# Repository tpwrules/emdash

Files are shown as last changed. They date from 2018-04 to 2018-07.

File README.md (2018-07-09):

# Installation Instructions

The code can be built both for an included Mac/Windows/Linux simulator and the LPC11C24 ARM microcontroller. Please follow these directions carefully to learn how to build the code. I assume you have a basic knowledge of command line operation.

## Building the Base

Building the base covers downloading the code and installing Python. Python is required to build the various data files.

#### Installing Git

The Git source control system is used to hold the code. You must install the Git client in order to download the code correctly.

* Download and install Git for your operating system from <https://git-scm.com/downloads>.
    * for the Windows installer, the default options are fine
* Clone the source code
    * open a command prompt and change to the directory you want the source to be downloaded to
    * execute `git clone https://github.com/tpwrules/emdash` to get the code

#### Installing Python

The Python scripting language is used to build data files and run the simulator. These directions have been tested with Python 3.6.6. They will most likely work with 3.5 and 3.6. Python 3.7 is not yet supported.

* Download and install the latest version of Python 3.6 for your operating system from <https://www.python.org/downloads/>
    * For the Windows installer, you must check "Add Python to Path" on the first page
    * Otherwise, the default options are fine

#### Installing Python Packages

Some Python packages are required to build the data files and run the simulator. Fortunately, Python makes them easy to install.

* Open up a command prompt.
* Run the command `python3 -m pip install pypng` or `py -3 -m pip install pypng` (on Windows)
* If python isn't found, close and re-open the command prompt.

#### Testing the Base

Now that the base has been prepared, it's time to test to make sure it works.

* Open a command prompt
* Change directories to the `dashboard` directory within the downloaded code
    * Hint: you can drag that folder into the command prompt instead of typing out its location
* Run the command `build_src_gen.py`. If you see the message `SOURCE GENERATED SUCCESSFULLY`, the base has been successfully built!

## Building for LPC11C24

Building for LPC11C24 requires a working install of the base. It does not require the simulator. I use the free MCUXpresso IDE for development on the LPC11C24. You must install it and import the project in order to deploy the code onto the chip.

#### Installing MCUXpresso
You can download the MCUXpresso 10.1.1 installer from [here](https://www.nxp.com/support/developer-resources/software-development-tools/mcuxpresso-software-and-tools/mcuxpresso-integrated-development-environment-ide:MCUXpresso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). Click the Download button, log in with an NXP account (required), then select 10.1.1 under the Previous tab. Version 10.2 seems to be broken, so don't use it.

Run the installer using all the default options. Make a workspace in your favorite place.

#### Importing the code
Now that the projects are downloaded, they can be imported into MCUXpresso.

* Select File -> Import
* Select to import Git -> Projects from Git and click Next
* Select the Existing local repository source and click Next.
* Click Add... and then Browse...
* Select the `emdash` folder in the code you downloaded and click OK.
* Check the `emdash\.git` repository in the results list and click Finish. 
* Select the `emdash` repository in the repository list and click Next twice, then Finish. Code import is now complete.

#### Building the code
Build the code for the chip by selecting the dash_11c24 project in the left pane and clicking the hammer icon in the top bar. If everything works, you will see a blue `Build finished` in the bottom window.

You can then use the green bug icon to program the chip with the code and enter the debugger. The first time you click the button, you will be asked to create a run configuration. Double-click the `C/C++ (NXP Semiconductor)` option in the left pane to create the correct configuration, then click Debug in the bottom to start it. Once this is done, the green button will launch the correct configuration automatically.

## Building for Simulation
A custom simulator is included which runs the same code that is downloaded on the chip. Running the simulator requires a working install of the base, but does not require MCUXpresso or the other LPC11C24 stuff. It also requires a compatible install of the Visual C++ Build Tools, which use several gigabytes of disk space.

#### Installing Python Packages
The simulator requires some additional Python packages to operate.

* Open a command prompt
* Run the command `python3 -m pip install cffi numpy pygame` or `py -3 -m pip install cffi numpy pygame` (on Windows)

#### Installing Visual C++ Build Tools
The build tools provide the compiler used to compile the application for simulation. You try to compile the application to see if the tools are already installed. If they are not, an installation is necessary.

* Open a command prompt
* Change directories to the `dashboard/pc` directory inside the code
* Run the command `build_pc_app.py`. If there are no errors, you're finished building for simulation
* If it says you need to install Visual C++ 14.0, a compatible version of the build tools could not be found.
* Download the Build Tools for Visual Studio 2017 installer from <https://go.microsoft.com/fwlink/?linkid=840931>.
* Once the main installer loads, check 'Visual C++ build tools' under the 'Workloads' tab and click Install
* Wait quite a while. Once finished, try to run the script again. If it says `PC APP BUILT SUCCESSFULLY`, you've successfully built the simulator and you should be able to run it by running `pc_app.py`.

## Installing the CAN libraries
The LPC11C24 code has a bootloader and PC-based programming application so that the devices can be reprogrammed over CAN. The simulator can generate and receive CAN messages for test purposes. Both of these functionalities require the installation of CAN libraries for Python and the appropriate hardware drivers.

#### Installing the Python libraries
* Open up a command prompt.
* Run the command `python3 -m pip install python-can` or `py -3 -m pip install python-can` (on Windows)

#### Installing the Vector drivers
The program uses Vector CAN interfaces. You can try to run the programming application to see if the correct drivers are already installed. If the Vector interface drivers are not installed, they are available [here](https://vector.com/vi_downloadcenter_en.html?type=Driver&formular_treffer_submit=1). Download the latest version of "Vector Driver Setup".

* Open a command prompt
* Change directories to balsdjfsldf
* Run `the bootloader program`. If you see the error message `The Vector API has not been loaded`, the drivers must be installed. If you see a different error, continue to dkjfas;.
* Run the Vector Driver Setup installer program. Select and install the interface types you wish to use.
* Driver installation is now complete.

#### Configuring the Vector drivers
The Vector drivers require you to create an application configuration, which tells the application which hardware to use.

* Open the Windows Control Panel and select the Vector Hardware option.
* Select Application -> Add in the top bar to create a new application.
* Name the application `emdash`, set 1 CAN channel and 0 for all other types, and click OK.
* Select Application -> emdash in the left pane, then right-click on CAN 1 and select the interface you wish to use. You may have to plug in your interface first.
* Close the window. Configuration is now complete.

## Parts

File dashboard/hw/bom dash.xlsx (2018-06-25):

Designation | Description | Mfg/# | Mouser # | RS # | Farnell # | Substitute | Quantity
C5, C4, C2 | 10nF 0603 >5V | Any | Any | Any | Any | Yes | 3
C6, C3, C1, C15, C17, C16, C14 | 100nF 0603 >5V | Any | Any | Any | Any | Yes | 7
C7 | 1nF 0603 | Any | Any | Any | Any | Yes | 1
C8, C10, C11 | 2.2uF 0603 X5R 25V | Murata GRM188R61E225ME84D | 81-GRM188R61E225ME4D | 915-9139 | 2576752 | Yes | 3
C9 | 22uF 0603 X5R 10V | Murata GRM188R61A226ME15D | 81-GRM188R61A226ME5D | 884-7258 | 2426957 | Yes | 1
C12, C13 | 39pF 0603 16V | Vishay VJ0603A390GXJPW1BC | 77-VJ0603A390GXJPBC | 652-0055 | 2496903 | Yes | 2
D1 | 40V 1A SMA Schottky Diode | Vishay SS14-E3/61T | 625-SS14-E3 | 638-7915 | 9551280 | Yes | 1
D2 | 22V 3kW Unidirectional SMA TVS Diode | Bourns SMLJ22A-Q | 652-SMLJ22A-Q | 172-3265 | 2839633 | Yes | 1
D3 | CAN bus TVS Diode | Nexperia PESD1CAN-UX | 771-PESD1CANUX | 136-4886 | 2357118 | No | 1
J1 | 2x10 2.54mm female header | Harwin M20-7831046 | 855-M20-7831046 | 681-6842 | 7992025 | Yes | 1
J2 | 2x5 1.27mm right angle shrouded male header | Samtec SHF-105-01-L-D-RA | 649-200215120001T4LF | 901-1850 | 2505002 | Yes | 1
J3 | 1x3 2.54mm connector | TE 281698-3 | 571-281698-3 | 532-096 | 1205991 | No | 1
J4 | 1x4 2.54mm connector | TE 281698-4 | 571-281698-4 | 532-103 | 1205992 | No | 1
L1 | 10uH SMD 1.3A 200mΩ | Coilcraft LPS4018-103MRB | 994-LPS4018-103MRB | Unavailable | 2408105 | No | 1
R2, R4 | 62Ω 0603 | Panasonic ERJ-3EKF62R0V | 667-ERJ-3EKF62R0V | 122-9377 | 2303039 | Yes | 2
R3, R1 | 10kΩ 0603 | Any | Any | Any | Any | Yes | 2
R5, R6, R7 | 100Ω 0603 | Any | Any | Any | Any | Yes | 3
R8 | 100kΩ 0603 | Any | Any | Any | Any | Yes | 1
R9 | 2MΩ 0603 1/10W 1% | Vishay CRCW06032M00FKEB | 71-CRCW06032M00FKEB | 679-0169 | 2447325 | Yes | 1
R10 | 383kΩ 0603 1/10W 1% | Yaego AC0603FR-07383KL | 603-AC0603FR-07383KL | Unavailable | 2138556 | Yes | 1
R11, R12 | 36Ω 1206 1/4W | Vishay CRCW120636R0FKEA | 71-CRCW1206-36-E3 | Unavailable | 2139306 | Yes | 2
RV1 | 10k side mounted trim pot | Bourns 3362X-1-103LF | 652-3362X-1-103LF | Unavailable | 2469481 | No | 1
SW1 | 2 position 2.54mm DIP switch | APM NDS02V | 642-NDS02V | 877-2113 | 2858862 | No | 1
U1 | NXP LPC11C24 microcontroller | NXP LPC11C24FBD48/301 | 771-LPC11C24FBD48301 | 741-3939 | 2314754 | No | 1
U2 | 28V 0.5A switching converter | Texas Instruments TPS62175DQCR | 595-TPS62175DQCR | 825-6955 | 2255013 | No | 1
U3 | 300mA LDO 3.3v regulator | Texas Instruments TLV70233QDBVRQ1 | 595-TLV70233QDBVRQ1 | 796-8326 | 2323652 | No | 1
Y1 | 12MHz 18pF HC49/US SMD | ABLS-12.000MHZ-B2-T | 815-ABLS-12-B2 | 703-1809 | 1652551 | Yes | 1

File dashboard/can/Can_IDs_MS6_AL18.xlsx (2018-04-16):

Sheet: CAN-Messages
Name | Benötigt für Datenauswertung | ID | Startbit | Lenght | Datentyp | Einheit | Grid MS6 Logging[ms] | Grid MS6 Sending [ms] | Erklärung
accv |  | 0x100 | 0 | 8 | 8 Bit signed | g | 10 ms | 10 ms | Beschleunigung wird durch das Speed Signal berechnet
accx |  | 0x100 | 8 | 16 | 16 Bit signed | g | 10 ms | 10 ms | Beschleunigung in x-Richtung
accy |  | 0x100 | 24 | 16 | 16 Bit signed | g | 10 ms | 10 ms | Beschleunigung in y-Richtung
accz |  | 0x100 | 40 | 16 | 16 Bit signed | g | 10 ms | 10 ms | Beschleunigung in z-Richtung
ath |  | 0x101 | 0 | 16 | 16 Bit unsigned | % | 2 ms | 10 ms | Drosselklappenstellung
B_autoshiften_ems |  | 0x101 | 16 | 8 | 8 Bit unsigned | Bool | 2 ms | 10 ms | Bit ob Autshift aktiv ist oder nicht
B_clutch_open |  | 0x101 | 24 | 8 | 8 Bit unsigned | Bool | 2 ms | 10 ms | Bit ob Kupplung aktiv ist oder nicht
B_clutchsw |  | 0x101 | 32 | 8 | 8 Bit unsigned | Bool | 2 ms | 10 ms | Bit ob Kupplungtaster aktiv ist oder nicht
B_cutoff_gc_ems |  | 0x101 | 40 | 8 | 8 Bit unsigned | Bool | 2 ms | 10 ms | Bit ob Gearcut aktiv ist oder nicht
B_dnshevent_ems |  | 0x101 | 48 | 8 | 8 Bit unsigned | Bool | 2 ms | 10 ms | Bit ob ein Downshiftevent erkannt wurde oder nicht
B_fan_ems |  | 0x101 | 56 | 8 | 8 Bit unsigned | Bool | 2 ms | 10 ms | Bit ob die generelle Lüfteransteuerung aktiviert ist
B_fpump |  | 0x102 | 0 | 8 | 8 Bit unsigned | Bool | 1 ms | 10 ms | Bit ob die generelle Benzinpumpenansteuerung aktiviert ist
B_func_lc |  | 0x102 | 8 | 8 | 8 Bit unsigned | Bool | 2 ms | 10 ms | Lambdaregelung durch Schalter aktiv
B_gc_err_ems |  | 0x102 | 16 | 8 | 8 Bit unsigned | Bool | 2 ms | 10 ms | Zeigt an ob ein Error während einem Schaltvorgang aufgetreten ist
B_ign_all |  | 0x102 | 24 | 8 | 8 Bit unsigned | Bool | 2 ms | 10 ms | Bit alle Einspritzungen sind aktiv
B_ignoff_gc_ems |  | 0x102 | 32 | 8 | 8 Bit unsigned | Bool | 2 ms | 10 ms | Zündungsaussetzer während Gearcut aktiv
B_ignoff_launch |  | 0x102 | 40 | 8 | 8 Bit unsigned | Bool | 2 ms | 10 ms | Zündungsaussetzer während Launchcontrol aktiv
B_inj_all |  | 0x102 | 48 | 8 | 8 Bit unsigned | Bool | 2 ms | 10 ms | Zündung aktiv
B_injoff_gc_ems |  | 0x102 | 56 | 8 | 8 Bit unsigned | Bool | 2 ms | 10 ms | Einspritzungsaussetzer während Gearcut
B_injoff_launch |  | 0x103 | 0 | 8 | 8 Bit unsigned | Bool | 2 ms | 10 ms | Einspritzungsaussetzer während Launchcontrol
B_launch |  | 0x119 | 16 | 8 | 8 Bit unsigned | Bool | 2 ms | 10 ms | Bit ob Launchcontrol aktiv ist oder nicht
B_launchsw |  | 0x103 | 8 | 16 | 16 Bit signed | Bool | 2 ms | 10 ms | Bit ob der Launchcontroltaster aktiv ist oder nicht
B_shiftdnsw |  | 0x119 | 24 | 16 | 16 Bit signed | Bool | 2 ms | 10 ms | Bit ob der Taster zum Runterschalten betätigt wurde
B_shiftupsw |  | 0x119 | 40 | 16 | 16 Bit signed | Bool | 2 ms | 10 ms | Bit ob der Taster zum Hochschalten betätigt wurde
B_upshevent_ems |  | 0x103 | 24 | 16 | 16 Bit signed | Bool | 2 ms | 10 ms | Bit ob ein Upshiftevent erkannt wurde oder nicht
clutch_pwm_ems |  | 0x103 | 40 | 8 | 8 Bit signed | % | 2 ms | 10 ms | PWM Signal der Kupplung
dam_fl |  | 0x120 | 0 | 16 | 16 Bit signed | mm | 2 ms | 10 ms | Federweg Dämpfer vorne links
dam_fr |  | 0x120 | 16 | 16 | 16 Bit signed | mm | 2 ms | 10 ms | Federweg Dämpfer vorne rechts
dam_rl |  | 0x120 | 32 | 16 | 16 Bit signed | mm | 2 ms | 10 ms | Federweg Dämpfer hinten links
dam_rr |  | 0x120 | 48 | 16 | 16 Bit signed | mm | 2 ms | 10 ms | Federweg Dämpfer hinten rechts
dnlaunch |  | 0x104 | 0 | 16 | 16 Bit signed | rpm | 2 ms | 10 ms | Differenz zwischen Zeil- und aktueller Drehzahl bei Launchcontrol
dnshiftcnt |  | 0x104 | 16 | 16 | 16 Bit unsigned | [none] | 2 ms | 10 ms | Zähler für Herunterschaltvorgang
dnshifterrcnt |  | 0x104 | 32 | 16 | 16 Bit unsigned | [none] | 2 ms | 10 ms | Errorzähler für das Herunterschalten
E_autoshiftsw |  | 0x103 | 48 | 8 | 8 Bit unsigned | [none] | 2 ms | 10 ms | Error Automatic Shifting Taster
E_clutchsw |  | 0x103 | 56 | 8 | 8 Bit unsigned | [none] | 2 ms | 10 ms | Error Kupplungstaster
E_gbctrl_ems |  | 0x104 | 48 | 8 | 8 Bit unsigned | [none] | 2 ms |  | Errorzustand der Gearbox Funktion
E_launchsw |  | 0x104 | 56 | 8 | 8 Bit unsigned | [none] | 2 ms |  | Error Launchcontroltaster
E_lsu |  | 0x105 | 0 | 8 | 8 Bit unsigned | [none] | 2 ms |  | Errorzustand der Lambdasonde
E_lsuh |  | 0x105 | 8 | 8 | 8 Bit unsigned | [none] | 2 ms |  | Errorzustand des Lambdasonden Heizers
E_pbrake_f |  | 0x105 | 16 | 8 | 8 Bit unsigned | [none] | 10 ms |  | Error Bremsdruck vorne
E_pbrake_r |  | 0x105 | 24 | 8 | 8 Bit unsigned | [none] | 10 ms |  | Error Bremsdruck hinten
E_pclutch |  | 0x105 | 32 | 8 | 8 Bit unsigned | [none] | 2 ms |  | Error Kupplungsdruck
E_poil |  | 0x105 | 40 | 8 | 8 Bit unsigned | [none] | 2 ms |  | Error Öldruck
E_speed |  | 0x105 | 48 | 8 | 8 Bit unsigned | [none] | 2 ms |  | Error vom Geschwindigkeitssignal
E_steer |  | 0x105 | 56 | 8 | 8 Bit unsigned | [none] | 10 ms |  | Error Lenkwinkelsignal
E_tfuel |  | 0x106 | 0 | 8 | 8 Bit unsigned | [none] | 2 ms |  | Error Benzintemperatur
E_thr |  | 0x106 | 8 | 8 | 8 Bit unsigned | [none] | 2 ms |  | Error Drosselklappensensor
E_tmot |  | 0x106 | 16 | 8 | 8 Bit unsigned | [none] | 2 ms |  | Error Motortemperatur
E_tmot2 |  | 0x106 | 24 | 8 | 8 Bit unsigned | [none] | 2 ms |  | Error Kühlwassertemperatur am Lüfter
E_toil |  | 0x106 | 32 | 8 | 8 Bit unsigned | [none] | 2 ms |  | Error Öltemperatur
E_ub |  | 0x106 | 40 | 8 | 8 Bit unsigned | [none] | 2 ms |  | Error Batteriespannung
fan_pwm_ems |  | 0x106 | 48 | 8 | 8 Bit unsigned | % | 2 ms
flc |  | 0x106 | 56 | 8 | 8 Bit unsigned | 0.005 | 2 ms
flc_i |  | 0x107 | 0 | 8 | 8 Bit signed | 0.005 | 2 ms
flc_p |  | 0x107 | 8 | 8 | 8 Bit signed | 0.005 | 2 ms
fpump_pi_pwm |  | 0x107 | 16 | 16 | 16 Bit unsigned |  | 1 ms
fpump_pre |  | 0x107 | 32 | 16 | 16 Bit unsigned |  | 1 ms
fpump_pwm |  | 0x107 | 48 | 16 | 16 Bit unsigned |  | 1 ms
fslip_acc |  | 0x108 | 0 | 8 | 8 Bit unsigned |  | 10 ms
gc_sherr_ct_ems |  | 0x108 | 8 | 8 | 8 Bit unsigned |  | 2 ms
gc_state_ems |  | 0x108 | 16 | 8 | 8 Bit unsigned |  | 2 ms
gear |  | 0x119 | 56 | 8 | 8 Bit signed | [none] | 2 ms
gear_gc_ems |  | 0x108 | 24 | 8 | 8 Bit signed |  | 2 ms
ign_bas |  | 0x108 | 32 | 8 | 8 Bit signed | ° | 2 ms
ign_gbctrl |  | 0x108 | 40 | 16 | 16 Bit signed | ° | 2 ms
ign_gc_ems |  | 0x108 | 56 | 16 | 16 Bit signed | ° | 2 ms
ign_gc_up_off_p2_ems |  | 0x110 | 0 | 16 | 16 Bit signed | ° | 2 ms
ign_gc_up_p2_ems |  | 0x110 | 16 | 16 | 16 Bit signed | ° | 2 ms
ign_out |  | 0x110 | 32 | 16 | 16 Bit signed | ° | 2 ms
lambda |  | 0x121 | 0 | 16 | 16 Bit unsigned | [none] | 2 ms
lamnom |  | 0x111 | 0 | 8 | 8 Bit unsigned | [none] | 2 ms
ltdist |  | 0x110 | 48 | 16 | 16 Bit unsigned |  | 1 s
mfuel_fpump |  | 0x111 | 8 | 16 | 16 Bit unsigned | mg/s | 1 ms
mi_launch |  | 0x111 | 24 | 8 | 8 Bit unsigned | % | 2 ms
nmot |  | 0x121 | 16 | 16 | 16 Bit unsigned | 1/min | 2 ms
nmotcgdn_ems |  | 0x111 | 32 | 16 | 16 Bit signed |  | 2 ms
nmotcgup_ems |  | 0x111 | 48 | 16 | 16 Bit signed |  | 2 ms
pbrake_f |  | 0x112 | 0 | 16 | 16 Bit unsigned | bar | 10 ms
pbrake_r |  | 0x112 | 16 | 16 | 16 Bit unsigned | bar | 10 ms
pclutch |  | 0x112 | 32 | 16 | 16 Bit unsigned | bar | 2 ms
pfuel |  | 0x121 | 32 | 8 | 8 Bit unsigned | bar | 2 ms
poil |  | 0x121 | 40 | 8 | 8 Bit unsigned | bar | 2 ms
rl |  | 0x112 | 48 | 16 | 16 Bit unsigned | % | 2 ms
shiftdn_pwm_ems |  | 0x113 | 0 | 8 | 8 Bit signed | % | 2 ms
slip_act |  | 0x113 | 8 | 16 | 16 Bit signed | % | 10 ms
slip_nom |  | 0x113 | 24 | 8 | 8 Bit unsigned | % | 10 ms
slip_nom_r |  | 0x113 | 32 | 8 | 8 Bit unsigned | % | 10 ms
slip_rl |  | 0x113 | 40 | 16 | 16 Bit signed | % | 10 ms
slip_rr |  | 0x114 | 0 | 16 | 16 Bit signed | % | 10 ms
speed |  | 0x121 | 48 | 16 | 16 Bit unsigned | km/h | 2 ms
steer |  | 0x114 | 16 | 16 | 16 Bit signed | ° | 10 ms
tecu_cpu |  | 0x113 | 56 | 8 | 8 Bit unsigned | °C | 10 ms
tecu_sys |  | 0x114 | 32 | 8 | 8 Bit unsigned | °C | 10 ms
tecu_sys2 |  | 0x114 | 40 | 8 | 8 Bit unsigned | °C | 10 ms
tfuel |  | 0x114 | 48 | 8 | 8 Bit unsigned | °C | 2 ms
tgc_arun_ems |  | 0x115 | 0 | 16 | 16 Bit unsigned | ms | 2 ms
tgc_block_ems |  | 0x115 | 16 | 16 | 16 Bit unsigned |  | 2 ms
tgc_dn_phs1_ems |  | 0x115 | 32 | 16 | 16 Bit unsigned |  | 2 ms
tgc_up_phs1_ems |  | 0x115 | 48 | 16 | 16 Bit unsigned |  | 2 ms
tgc_up_phs2_ems |  | 0x116 | 0 | 16 | 16 Bit unsigned |  | 2 ms
THMM_01_1 |  | 0x600 | 0 | 16 | 16 Bit signed |  | 500 ms |  | Externe Temperatursensorbox
THMM_02_1 |  | 0x600 | 16 | 16 | 16 Bit signed |  | 500 ms |  | Externe Temperatursensorbox
THMM_03_1 |  | 0x600 | 32 | 16 | 16 Bit signed |  | 500 ms |  | Externe Temperatursensorbox
THMM_04_1 |  | 0x600 | 48 | 16 | 16 Bit signed |  | 500 ms |  | Externe Temperatursensorbox
THMM_05_1 |  | 0x601 | 0 | 16 | 16 Bit signed |  | 500 ms |  | Externe Temperatursensorbox
THMM_06_1 |  | 0x601 | 16 | 16 | 16 Bit signed |  | 500 ms |  | Externe Temperatursensorbox
THMM_07_1 |  | 0x601 | 32 | 16 | 16 Bit signed |  | 500 ms |  | Externe Temperatursensorbox
THMM_08_1 |  | 0x601 | 48 | 16 | 16 Bit signed |  | 501 ms |  | Externe Temperatursensorbox
tinj |  | 0x116 | 16 | 16 | 16 Bit unsigned |  | 2 ms
tint |  | 0x114 | 56 | 8 | 8 Bit unsigned |  | 2 ms
tmot |  | 0x122 | 0 | 8 | 8 Bit unsigned | °C | 2 ms
tmot2 |  | 0x122 | 8 | 8 | 8 Bit unsigned | °C | 2 ms
toil |  | 0x122 | 16 | 8 | 8 Bit unsigned | °C | 2 ms
uautoshiftsw |  | 0x116 | 32 | 16 | 16 Bit unsigned |  | 2 ms
ub |  | 0x122 | 24 | 16 | 16 Bit unsigned | V | 1 ms
uclutchsw |  | 0x116 | 48 | 16 | 16 Bit unsigned |  | 2 ms
udam_fl |  | 0x117 | 0 | 16 | 16 Bit unsigned |  | 2 ms
udam_fr |  | 0x117 | 16 | 16 | 16 Bit unsigned |  | 2 ms
udam_rl |  | 0x117 | 32 | 16 | 16 Bit unsigned |  | 2 ms
udam_rr |  | 0x117 | 48 | 16 | 16 Bit unsigned |  | 2 ms
ugearp |  | 0x118 | 0 | 16 | 16 Bit unsigned |  | 2 ms
ulaunchsw |  | 0x118 | 16 | 16 | 16 Bit unsigned |  | 2 ms
upclutch |  | 0x118 | 32 | 16 | 16 Bit unsigned |  | 2 ms
upshiftcnt |  | 0x118 | 48 | 16 | 16 Bit unsigned |  | 2 ms
upshifterrcnt |  | 0x119 | 0 | 16 | 16 Bit unsigned |  | 2 ms
vwheel_fl |  | 0x123 | 0 | 16 | 16 Bit unsigned | km/h | 2 ms
vwheel_fr |  | 0x123 | 16 | 16 | 16 Bit unsigned | km/h | 2 ms
vwheel_rl |  | 0x123 | 32 | 16 | 16 Bit unsigned | km/h | 2 ms
vwheel_rr |  | 0x123 | 48 | 16 | 16 Bit unsigned | km/h | 2 ms
B_als |  |  |  |  | 8 Bit unsigned |  | 2 ms
B_autoshiftsw |  |  |  |  | 8 Bit unsigned |  | 2 ms
B_autoshiftsw_can |  |  |  |  | 8 Bit unsigned |  | 2 ms
B_brakepos |  |  |  |  | 8 Bit unsigned |  | 2 ms
B_clutchsw_can |  |  |  |  | 8 Bit unsigned |  | 2 ms
B_cutoff_gc |  |  |  |  | 8 Bit unsigned |  | 2 ms
B_drs_ems |  |  |  |  | 8 Bit unsigned |  | 10 ms
B_drs_plaus_ems |  |  |  |  | 8 Bit unsigned |  | 10 ms
B_fpump_man |  |  |  |  | 8 Bit unsigned |  | 1 ms
B_fpump_pre |  |  |  |  | 8 Bit unsigned |  | 1 ms
B_gc |  |  |  |  | 8 Bit unsigned |  | 2 ms
B_gearlevpos |  |  |  |  | 8 Bit unsigned |  | 10 ms
B_ignoff_gc |  |  |  |  | 8 Bit unsigned | Bool | 2 ms
B_la_blocked |  |  |  |  | 8 Bit unsigned |  | 2 ms
B_lamadap |  |  |  |  | 8 Bit unsigned |  | 2 ms
B_lamadap_st |  |  |  |  | 8 Bit unsigned |  | 2 ms
B_lamnom_low |  |  |  |  | 8 Bit unsigned |  | 2 ms
B_launchsw_can |  |  |  |  | 8 Bit unsigned |  | 2 ms
B_lc |  |  |  |  | 8 Bit unsigned |  | 10 ms
B_lc_leanprot |  |  |  |  | 8 Bit unsigned |  | 2 ms
B_lcen_rl |  |  |  |  | 8 Bit unsigned |  | 2 ms
B_lsuop |  |  |  |  | 8 Bit unsigned |  | 2 ms
B_norunshifttest_ems |  |  |  |  | 8 Bit unsigned | Bool | 2 ms |  | Bit ob ein Schalttest aktiv ist, wenn der Motor aus ist
B_pfuel |  |  |  |  | 8 Bit unsigned |  | 10 ms
B_pitspeedsw |  |  |  |  | 8 Bit unsigned |  | 2 ms
B_pitspeedsw_can |  |  |  |  | 8 Bit unsigned |  | 2 ms
B_poil |  |  |  |  | 8 Bit unsigned |  | 10 ms
B_psdia_fpump_ol |  |  |  |  | 8 Bit unsigned |  | 1 ms
B_psdia_fpump_ot |  |  |  |  | 8 Bit unsigned |  | 1 ms
B_psdia_fpump_scb |  |  |  |  | 8 Bit unsigned |  | 1 ms
B_psdia_fpump_scg |  |  |  |  | 8 Bit unsigned |  | 1 ms
B_pwr |  |  |  |  | 8 Bit unsigned |  | 2 ms
B_startbrake |  |  |  |  | 8 Bit unsigned |  | 2 ms
B_stend |  |  |  |  | 8 Bit unsigned |  | 2 ms
B_tdlcen_st |  |  |  |  | 8 Bit unsigned |  | 2 ms
B_temin |  |  |  |  | 8 Bit unsigned |  | 2 ms
B_tfuel |  |  |  |  | 8 Bit unsigned |  | 10 ms
B_tmlcen |  |  |  |  | 8 Bit unsigned |  | 2 ms
B_tmot |  |  |  |  | 8 Bit unsigned |  | 10 ms
B_tmot2 |  |  |  |  | 8 Bit unsigned |  | 10 ms
B_toil |  |  |  |  | 8 Bit unsigned |  | 10 ms
B_trans_acc |  |  |  |  | 8 Bit unsigned |  | 2 ms
B_trans_dec |  |  |  |  | 8 Bit unsigned |  | 2 ms
B_transcomp |  |  |  |  | 8 Bit unsigned |  | 2 ms
B_transcomp_en |  |  |  |  | 8 Bit unsigned |  | 2 ms
B_trq_gbctrl |  |  |  |  | 8 Bit unsigned |  | 2 ms
B_trq_gbctrl_ems |  |  |  |  | 8 Bit unsigned |  | 2 ms
B_wetsw |  |  |  |  | 8 Bit unsigned |  | 2 ms
B_wetsw_can |  |  |  |  | 8 Bit unsigned |  | 2 ms
brakepos |  |  |  |  | 16 Bit signed |  | 2 ms
brakepos_cal |  |  |  |  | 16 Bit signed |  | 2 ms
brakepos_grd |  |  |  |  | 16 Bit signed |  | 2 ms
brakepos_raw |  |  |  |  | 16 Bit signed |  | 2 ms
cutoff_gc |  |  |  |  | 16 Bit unsigned |  | 2 ms
cutoff_gc_ems |  |  |  |  | 16 Bit unsigned | [none] | 2 ms
dam_fl_r |  |  |  |  | 16 Bit signed | mm | 2 ms
dam_fl_raw |  |  |  |  | 16 Bit signed | mm | 2 ms
dam_fr_r |  |  |  |  | 16 Bit signed | mm | 2 ms
dam_fr_raw |  |  |  |  | 16 Bit signed | mm | 2 ms
dam_rl_r |  |  |  |  | 16 Bit signed | mm | 2 ms
dam_rl_raw |  |  |  |  | 16 Bit signed | mm | 2 ms
dam_rr_r |  |  |  |  | 16 Bit signed | mm | 2 ms
dam_rr_raw |  |  |  |  | 16 Bit signed | mm | 2 ms
disttrip |  | 0x104 | 0 | 16 | 16 Bit unsigned | km | 1 s |  | Gefahrene Distanz seit letztem Reset des MS6
drs_freq_ems |  |  |  |  | 16 Bit unsigned |  | 10 ms
drs_pwm_ems |  |  |  |  | 8 Bit unsigned |  | 10 ms
E_autoshiftsw_can |  |  |  |  | 8 Bit unsigned | [none] | 2 ms
E_brakepos |  |  |  |  | 8 Bit unsigned | [none] | 2 ms
E_clutchsw_can |  |  |  |  | 8 Bit unsigned |  | 2 ms
E_gear_can |  |  |  |  | 8 Bit unsigned |  | 2 ms
E_gearpoti |  |  |  |  | 8 Bit unsigned |  | 2 ms
E_launchsw_can |  |  |  |  | 8 Bit unsigned |  | 2 ms
E_p22 |  |  |  |  | 8 Bit unsigned |  | 2 ms
E_p22_2 |  |  |  |  | 8 Bit unsigned |  | 2 ms
E_pitspeedsw |  |  |  |  | 8 Bit unsigned |  | 2 ms
E_pitspeedsw_can |  |  |  |  | 8 Bit unsigned |  | 2 ms
E_psdia_fpump |  |  |  |  | 8 Bit unsigned | [none] | 1 ms |  | Error Benzinpumpenansteuerung
E_psdia_fpump_ecfp |  |  |  |  | 8 Bit unsigned |  | 1 ms
E_thr2 |  |  |  |  | 8 Bit unsigned | [none] | 2 ms
E_tint |  |  |  |  | 8 Bit unsigned | [none] | 2 ms
E_tint2 |  |  |  |  | 8 Bit unsigned | [none] | 2 ms
E_wetsw |  |  |  |  | 8 Bit unsigned |  | 2 ms
E_wetsw_can |  |  |  |  | 8 Bit unsigned |  | 2 ms
f_inj_gbctrl |  |  |  |  | 16 Bit signed |  | 2 ms
f_injgc_ems |  |  |  |  | 8 Bit unsigned | 0.01 | 2 ms
Fan_Current |  |  |  |  | 16 Bit unsigned |  | 2 ms
Fan_Power |  |  |  |  | 16 Bit unsigned |  | 2 ms
Fan_Voltage |  |  |  |  | 16 Bit unsigned |  | 2 ms
fpump_2p_pwm |  |  |  |  | 16 Bit unsigned |  | 1 ms
fpump_ub |  |  |  |  | 8 Bit unsigned |  | 1 ms
Fuel_Pump_Current |  |  |  |  | 16 Bit unsigned |  | 2 ms
Fuel_Pump_Power |  |  |  |  | 16 Bit unsigned |  | 2 ms
Fuel_Pump_Voltage |  |  |  |  | 16 Bit unsigned |  | 2 ms
gearlevacc_fil |  |  |  |  | 32 Bit float |  | 2 ms
gearlevacc_max |  |  |  |  | 32 Bit unsigned |  | 2 ms
gearlevpos_cal |  |  |  |  | 16 Bit signed |  | 2 ms
gearlevpos_grd |  |  |  |  | 16 Bit signed |  | 2 ms
gearlevruck_fil |  |  |  |  | 32 Bit float |  | 2 ms
gearlevruck_max |  |  |  |  | 32 Bit unsigned |  | 2 ms
gearlevspeed_fil |  |  |  |  | 32 Bit float |  | 2 ms
gearlevspeed_max |  |  |  |  | 32 Bit unsigned |  | 2 ms
handling1 |  |  |  |  | 16 Bit signed |  | 10 ms
handling2 |  |  |  |  | 16 Bit signed |  | 10 ms
lamctrl_i |  |  |  |  | 8 Bit unsigned |  | 2 ms
lamctrl_p |  |  |  |  | 8 Bit unsigned |  | 2 ms
pclutch_r |  |  |  |  | 16 Bit unsigned |  | 2 ms
pwrstg_diag_ecc |  |  |  |  | 32 Bit unsigned |  | 2 ms
time_day |  |  |  |  | 8 Bit unsigned |  | 10 ms
time_hour |  |  |  |  | 8 Bit unsigned |  | 10 ms
time_min |  |  |  |  | 8 Bit unsigned |  | 10 ms
time_mon |  |  |  |  | 8 Bit unsigned |  | 10 ms
time_sec |  |  |  |  | 8 Bit unsigned |  | 10 ms
time_year |  |  |  |  | 8 Bit unsigned |  | 10 ms
ubrakepos |  |  |  |  | 16 Bit unsigned |  | 2 ms
ulaunchsw_can |  |  |  |  | 8 Bit unsigned |  | 2 ms
upitspeedsw |  |  |  |  | 16 Bit unsigned |  | 2 ms
upitspeedsw_can |  |  |  |  | 8 Bit unsigned |  | 2 ms
uwetsw |  |  |  |  | 16 Bit unsigned |  | 2 ms
uwetsw_can |  |  |  |  | 8 Bit unsigned |  | 2 ms
wheeltravel_fl |  |  |  |  | 32 Bit float |  | 2 ms
wheeltravel_fr |  |  |  |  | 32 Bit float |  | 2 ms
wheeltravel_rl |  |  |  |  | 32 Bit float |  | 2 ms
wheeltravel_rr |  |  |  |  | 32 Bit float |  | 2 ms

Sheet: Freie Bytes in CAN-IDs
CAN-ID | Freies Byte
0x100 | 7
0x122 | 5,6,7

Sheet: Info
Little Endian wird verstanden

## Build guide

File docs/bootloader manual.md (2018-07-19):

Welcome to the manual for the bootloader. The bootloader is designed to be easy and safe to use. This manual is divided into two sections. [Overview](#overview) describes the tasks and features of the bootloader. [PC Programmer](#pc-programmer) describes how to use the included PC-based programmer software.

The protocol is documented in `boot/src_11c24/protocol.h`.

# Overview

## Features

The bootloader allows the internal Flash memory of the LPC11C24 to be programmed over the CAN bus. The bootloader can survive a corrupt or buggy application, an incomplete flash, or even power loss while programming. The bootloader also has a system ID to allow multiple bootloaders to exist on the same CAN bus without interference.

## Application

The application is launched by the bootloader. It is protected from corruption by a CRC32 checksum. If the checksum is incorrect, the bootloader will refuse to start the application.

There are 28KiB (28,672 bytes) available for the application. The application memory image is generated by the MCUXpresso software and programmed by the bootloader directly into flash starting at address 0x4000.

The following application memory images are used:

* The dashboard application: `dash_11c24/Debug/dash_11c24.bin`
* The wheelboard application: `wheel_11c24/Debug/wheel_11c24.bin`

## Boot Process

After the device is powered on or reset, the bootloader starts. It begins by verifying its own code. If verification fails, the bootloader halts. It then verifies the application. If the application is valid, the bootloader waits 250ms for a connection, then starts the application. If the application is not valid, the bootloader waits indefinitely for a connection.

Once the application starts, it also listens for a connection. If a connection is attempted, the application restarts the bootloader, which then waits indefinitely for the connection. If the application has a bug and does not restart the bootloader, the device can be manually reset to attempt a connection within the 250ms window.

# PC Programmer

## Usage

The PC programmer is very easy to use. It uses the Vector hardware to program the device over CAN.

Programming is accomplished with the following steps:

* Build the new application in MCUXpresso.
* Connect the Vector hardware to your computer and the bus the device is on.
* Turn on the device, if it is not already on.
* Open a command prompt and change to the `boot_pc` directory.
* Run the programmer `pc_programmer.py` with the path to the application memory image.
* If the programmer says `Tasks Complete`, programming was successful.

## Examples

To get help with the program:

`pc_programmer.py -h`

To program the dashboard (on Windows):

`pc_programmer.py ..\dash_11c24\Debug\dash_11c24.bin`

To check the current application in the dashboard:

`pc_programmer.py -d dashboard -c`

or

`pc_programmer.py ..\dash_11c24\Debug\dash_11c24.bin -c`

To check the the version of the application binary image:

`pc_programmer.py ..\dash_11c24\Debug\dash_11c24.bin -i`

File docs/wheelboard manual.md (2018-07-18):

Welcome to the manual for the Einstein Motorsport Wheelboard. The wheelboard is designed to be easy to use, and customizable for any application. This manual is divided into three sections. [Usage](#usage) describes how to use the wheelboard's hardware and current firmware. [Customizing](#customizing) describes how to customize the wheelboard. [Programming](#programming) describes the architecture of the firmware and the functions available to customizers.

# Usage

## Wiring

Input buttons should be wired between GND and the corresponding input pin. The traction control knob should be wired with the 0 side connected to GND, the 11 side connected to 3.3V, and the switch output connected to the corresponding input pin.

The current input assignments are as follows:

Input | Button | Message
----- | ------ | -------
A1 | Traction control knob | wb_traction_knob
A2 | Unused | N/A
A3 | Unused | N/A
A4 | Unused | N/A
B1 | Clutch | wb_clutch
B2 | Upshift | wb_upshift
B3 | Downshift | wb_downshift
B4 | Radio | wb_radio
B5 | Launch | wb_launch
C1 | Dash mode | wb_dash_mode
C2 | Lap | wb_lap
C3 | Autoshift | wb_autoshift
C4 | Unused | N/A
C5 | Unused | N/A

## Hardware

The wheelboard has three input ports: A (four pins), B (five pins), and C (five pins). All pins support input between 0V and 3.3V. Voltages outside this range may damage the wheelboard.

Each input has configurable pull-up and pull-down resistors. Pins on port A can also be read by a 10 bit analog-to-digital converter. All pins can be configured for output mode, but this functionality is not used in the current firmware or exposed to the CAN bus.

The inputs are connnected to the processor according to the following table:

Input | Processor Pin | ADC Channel
----- | ------------- | -----------
A1 | PIO0_11 | ADC_CH0
A2 | PIO1_0 | ADC_CH1
A3 | PIO1_1 | ADC_CH2
A4 | PIO1_2 | ADC_CH3
B1 | PIO2_8 | ADC unsupported
B2 | PIO0_6 | ADC unsupported
B3 | PIO0_7 | ADC unsupported
B4 | PIO0_8 | ADC unsupported
B5 | PIO0_9 | ADC unsupported
C1 | PIO2_1 | ADC unsupported
C2 | PIO0_3 | ADC unsupported
C3 | PIO1_8 | ADC unsupported
C4 | PIO0_2 | ADC unsupported
C5 | PIO2_7 | ADC unsupported

# Programming

This section explains how the firmware works and the functions available to customizers.

The following topics are covered:
* Application and Main Loop
* Button Processor
* Button Reading

## Application and Main Loop

The application receives the timer interrupt and contains the main loop. When the application starts up, the buttons are initialized by calling `br_read()`. Then, the main loop waits for interrupts.

When the timer interrupt is received every millisecond, the button processor `bp_process()` is called. Then, the CAN messages are transmitted, if necessary. The version message is sent every second and the button messages are sent as soon as they change, or every 50 milliseconds if there is no change.

The application code is contained in `src_11c24/app.c`.

## Button Processor

The button processor is the heart of the application. Every button has an unsigned 8 bit value representing the button's current state. When the timer elapses, the processor reads the new state of each button by calling its update function. It then debounces each button and transmits the new state, if any, on the CAN bus. All buttons are read every millisecond, so the time spent in button update functions cannot exceed one millisecond.

Buttons do not have assigned inputs. The update function for a button may read multiple inputs, or multiple update functions may read the same input.

### Debouncing

The debounce algorithm helps remove electrical and contact noise from the input. It operates on the button's current state (what is sent over CAN), the new state (what the processor measured this millisecond), and the previous new state (what the processor measured last millisecond). The algorithm waits until the button's new state has been consistent for a period of time before accepting it as the current state.

If the current state does not match the new state, and the new state is non-0 and matches the previous new state for 10 consecutive milliseconds (default debounce press time), the current state becomes the new state.

If the current state does not match the new state, and the new state is 0 and matches the previous new state for 50 consecutive milliseconds (default debounce release time), the current state becomes the new state.

The debounce press and release times are configurable per-button. Once the current state has changed, it is scheduled for immediate transmission on the CAN bus.

## Button Reading

Reading the value of the board inputs is done using hardware-specific functions for the LPC11C24's IOCON, GPIO, and ADC peripherals. Covering these functions is outside the scope of this documentation. You can consult the BLALAH for information on using the peripherals. The implemention of the traction knob may be useful as a reference for the ADC peripheral.

The input hardware for all buttons is initialized in `br_init()`. This function is called once when the board starts up. The button's input hardware is then read in the button's update function.

For the case of a "simple" button, macros are provided to handle initialization and updating. A "simple" button is defined as the following:

* The physical switch connects one input to GND when pressed.
* The physical switch disconnects that input when released (or connects it to 3.3V).
* The button's state is 1 when pressed and 0 when released.

If the button has an update function called `<update>` and the physical switch is connected to input `<pin>` (e.g. A3 or C5), then the following macros are available:

* `BR_SIMPLE_INIT(<update>, PIN_<pin>)` initializes the button's input. Put this macro in the `br_init()` function.
* `BR_SIMPLE(<update>, PIN_<pin>)` creates a button update function. Put this macro in the `button_read.c` file. 

# Customizing

This section contains the specific steps required to perform customizations to the firmware.

The following tasks are covered:

* Adding a Button

## Adding a Button

Button definitions are stored in `buttons/buttons.py` as Python objects. Adding a button is done by instantiating a Python `Button` object and adding it to the list of `buttons` in the file. If `<name>` is the button's name, then `btn_<name>` is the data structure which holds its value (a `button_state_t`) and `BTN_ID_<name in uppercase>` is defined as its ID in the data structure array.

The `Button` constructor has the following arguments:
* `name` is the name of the button.
* `msg_id` is the 11-bit CAN message ID which contains the button's state.
* `byte` is the byte within the message which contains the button's state.
* `update` is the C function to call to update this button.
* `debounce_press` is the debounce press time in milliseconds. Consult the Debouncing section.
* `debounce_release` is the debounce release time in milliseconds. Consult the Debouncing section.

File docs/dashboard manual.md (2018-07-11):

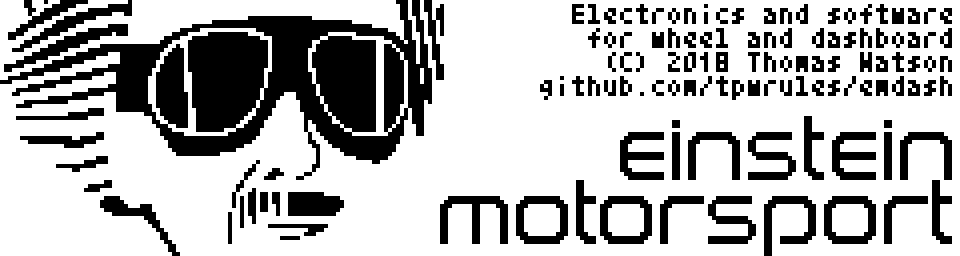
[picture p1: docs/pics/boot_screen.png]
boot screen


Welcome to the manual for the Einstein Motorsport Dashboard. The dashboard is designed to be easy to use, and customizable for any application. This manual is divided into three sections. [Usage](#usage) describes how to use the dashboard's current firmware. [Customizing](#customizing) describes how to customize the dashboard. [Programming](#programming) describes the architecture of the firmware and the functions available to customizers.

# Usage

## Main Screen

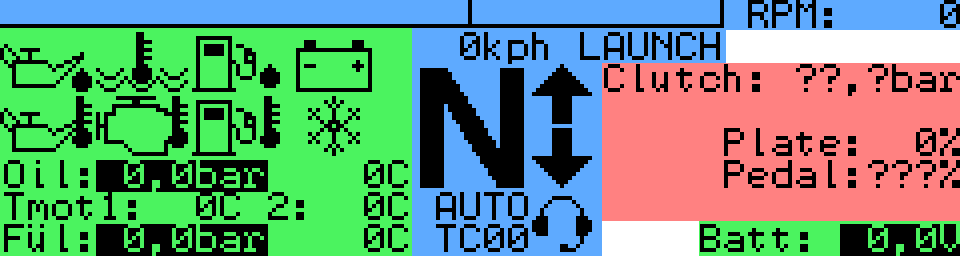
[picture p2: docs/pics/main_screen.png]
main screen


The main screen is divided into three sections:
* Car Information (green)
* Driver Information (blue)
* Mode Area (red)

### Car Information

This sections displays the measurements and status of the car's systems. Warning icons are displayed when certain thresholds are exceeded. When an icon is displayed, the corresponding measurement is drawn with inverted color.

Display of the section is handled by `src/warn.c`.

#### Measurement Description
The meaning of each measurement icon is described below. The table describes the icons in left to right, top to bottom order. The "Variable" column tells which canvar is monitored. The "Limit" column is the constant in `src/limits.h` which controls the value at which it should happen.

Variable | Limit | Displayed when
-------- | ----- | --------------
poil | LIM_OIL_PRESSURE_MIN | Oil pressure is too low.
tmot2 | LIM_WATER_TEMP_MAX | Cooling water temperature is too high.
pfuel | LIM_FUEL_PRESSURE_MIN | Fuel pressure is too low.
ub | LIM_BATTERY_MIN | Battery voltage is too low (as measured by ECU).
toil | LIM_OIL_TEMP_MAX | Oil temperature is too high.
tmot | LIM_BLOCK_TEMP_MAX | Engine temperature is too high.
tfuel | LIM_FUEL_TEMP_MAX | Fuel temperature is too high.
toil | LIM_OIL_TEMP_MIN | Engine oil temperature is too low.

### Driver Information

This area displays status and measurements important to the driver. Display of this section is handled by `src/drive.c`.

The following measurements are displayed:

* The RPM bar and current engine RPM (`nmot`) are displayed the top of the screen. When the current RPM exceeds the optimal RPM (illustrated by the black line), the entire screen flashes to prompt the driver to upshift. This is configurable in `src/limits.h` as well.
* Current gear (`gear`) is displayed in the center of the screen.
* If the upshift paddle on the wheel is pressed (`wb_upshift != 0`), an up arrow is displayed next to the gear indicator.
* If the downshift paddle on the wheel is pressed (`wb_downshift != 0`), a down arrow is displayed next to the gear indicator.
* If automatic shifting is enabled (`B_autoshiften_ems != 0`), AUTO is displayed below the gear indicator.
* Current speed (`speed`) is displayed above the gear indicator.
* If launch control is active (`B_launch != 0`), LAUNCH is displayed next to the current speed.
* If the radio button on the wheel is pressed (`wb_radio != 0`), a headset icon is displayed.
* Current traction control level (`wb_traction_knob`) is displayed at the bottom center of the screen.

### Mode Area

This area displays various other pieces of information, in several different modes. The mode is switched using the dash mode button on the wheel. The available modes are described below, in selection order.

CAN Status mode is handled in `canvar.c`, Firmware Version mode is handled in `src/version.c`, and all other modes are handled in `src/modes.c`.

#### Firmware Version

This page displays the firmware versions of the dashboard and wheelboard. The first number is the Git commit hash the firmware was built from, and the second number is the time it was built in YYYYMMddhhmm format. It is displayed briefly at startup, then the dashboard automatically switches to the next mode.

#### Clutch and Throttle

This page displays the clutch system pressure (`pclutch`). It also displays the position of the throttle pedal (???) and the throttle plate (`ath`).

#### CAN Status

This page displays the status of the CANBUS engine. If there is an error, this page is automatically shown. It also displays the current CPU usage of the dashboard processor. All messages will be processed, so high CPU usage will not result in incorrect operation. High CPU usage may slow down display updates; however, the latest data will always be shown. This is not a problem unless the CPU usage is 100% for long periods of time.

# Customizing

This section contains the specific steps required to perform customizations to the firmware.

The following tasks are covered:
* Adding a Canvar
* Adding a Picture
* Writing a Canvar Callback
* Writing a Mode Function

## Adding a Canvar

Canvar definitions are stored in `can/canvars.py` as Python objects. Adding a canvar is done by instantiating a Python `Variable` object and adding it to the list of `variables` in the file. Once this is completed, the variable can be used. If `<name>` is the variable's name, `cv_<name>` is the data structure which holds its value (a `canvar_state_t`) and `CV_ID_<name in uppercase>` is defined as its ID in the data structure array.

The `Variable` constructor has the following arguments:
* `name` is the name of the variable.
* `msg_id` is the 11-bit CAN message ID which contains the variable. If `None`, the variable has no associated ID and can only set with `app_canvar_interrupt`. The message is processed as little endian.
* `size` is the size, 1-32 bits, of the variable.
* `start` is the start, 0-63 bits, of the variable within the message. Bit 0 is LSB of byte 0 in the message, and bit 63 is MSB of byte 7 in the message.
* `signed=False`: if True, the variable is sign-extended to 32 bits.
* `multiplex=None` is the Multiplexer Value for this variable. If None, the message is not multiplexed.
* `callback=None` is the C function to call when this variable is updated with a new value. If None, nothing is called.

## Adding a Picture

Picture definitions are stored in `pics/piclist.py` as Python objects. Adding a picture is done by instantiating a Python `Picture` object and adding it to the `piclist` in the file. Once this is completed, the picture can be used. If `<name>` is the picture's name, its ID is defined as `PIC_ID_<name in uppercase>`. 

The `Picture` constructor has the following arguments:
* `path` is the file system path to the PNG file with the image data, relative to `pics/`.
* `name` is the name of the picture.
* `area=None` is the area of the original image to use, or None to use the whole image. It is a tuple with the following numbers, in pixels: `(<upper left corner of picture, x coordinate>, <upper left corner of picture, y coordinate>, <picture width>, <picture height>)`.

## Writing a Canvar Callback

When a canvar is changed, its callback is called to act on that change.

Callback functions have the following prototype: `void callback(uint32_t val)`, where `val` is the value of the canvar at the time the callback is called. It is sign or zero extended to 32 bits according to the `signed` parameter of the `Variable`.

The callback likely wants to change the screen based on the value of the canvar. Standard C functions like `sprintf` can be used to build the value, and the screen functions covered elsewhere can be used to update the screen. If the callback updates the screen in the mode area, it should check that `app_mode_change_func` equals the correct function, so that it only draws if the mode is actively being displayed.

The callback function is called with interrupts enabled. Interrupts can be disabled when necessary, but they should be enabled while screen functions are called.

If you want the canvar function to be called the next time the canvar is refreshed, even if the new value is the same as the old one, call `CV_CALL_NEXT_UPDATE(cv_<name>)` at the end of the function with interrupts disabled. Operations on other canvars are also possible.

## Writing a Mode Function

A mode function handles displaying and updating a dash mode. It has two jobs: to prepare the mode area of the screen for the current mode, and to update `app_mode_change_func` with the pointer to the next mode function.

Mode functions have the following prototype: `void mode_func(bool next)`. If `next` is `true`, the function should set `app_mode_change_func` to the next mode function and return. If `false`, the function can prepare the screen.

Preparing the screen usually involves drawing placeholder values and labels. The mode function should also call `CV_RENEW(cv_<name>)` with all of the canvars which are displayed in that mode, so that they will be immediately redrawn.

# Programming

This section explains how the firmware works and the functions available to customizers.

The firmware is divided into four distinct sections:
* Application and Main Loop
* Canvar System and Variable Handlers
* Screen
* Platform

## Application and Main Loop

The application receives the timer interrupt and contains the main loop. The main loop calls the variable handlers when there are new values.

The application is responsible for dash mode changes. It clears the screen in preparation for a mode change and calls the appropriate functions to coordinate the change. The variable `app_mode_change_func` should point to the mode change function. More details are in the customizer manual.

The application code is contained in `src/app.c`. This file also has helper routines which may be useful across the application.

### Application Operations

The following operations change the state of the application:
* `void app_show_next_mode(void)` shows the next dash mode by clearing the mode area of the screen, then calling the function pointed to by `app_mode_change_func` with a `false` value.

The following helper routines are available:
* `uint32_t hysteresis(uint32_t old, uint32_t new, uint32_t max_delta)` applies hysteresis to a value. If the difference between `new` and `old` is greater than `max_delta`, the function returns `new`. Otherwise, it returns `old`. `old` should be the previous return value of the function.
* `uint32_t hysteresis_div(uint32_t old, uint32_t new, uint32_t divisor)` applies hysteresis to `new`, then returns it divided by `divisor`. `divisor` must be a multiple of 4, or the returned value will be incorrect. `old` should be the previous return value of the function; it has already been divided.

## Canvar System and Variable Handlers

The canvar (CAN variable) system is responsible for parsing incoming CAN messages and storing new variable values in memory. The main loop then calls a function for each variable that acts on its new value.

Canvars are defined in the canvar database. Defining a new canvar is covered in the customizer manual.

The canvar processor is contained in `src/canvar.c`. The canvar database is automatically generated by `can/canvars.py`. The generated canvar database is contained in `src_gen/canvar_defs.c` and `src_gen/canvar_defs.h`.

### Canvar Operations

NOTE: All canvar operations must be done with interrupts disabled!

If a canvar has a specific `<name>`, then `cv_<name>` is the data structure which holds its value (a `canvar_state_t`) and `CV_ID_<name in uppercase>` is defined as its ID in the data structure array.

The following operations on canvars are supported:
* `CV_RENEW(cv_<name>)` re-sets a variable to new as long as as it is a valid value.
* `CV_CALL_NEXT_UPDATE(cv_<name>)` re-sets a variable to invalid as long as it is not a new value. This has the effect that the next update to that variable, even if it is the same value, will call the callback.

## Screen

The dashboard is displayed on a 240x64 graphic LCD using the RA6963 controller. Please consult `src/screen.h` for documentation on the screen functions.

## Platform

The platform interfaces between the application and hardware. If you would like to call the platform interrupt functions from within the application, interrupts must be turned off!

The platform code for the simulator is contained in `pc/platform_pc.h` and in the simulator itself. The platform code for the real device is contained in `src_11c24/`

The plaform calls the following interrupt functions in the application to perform work:
* `void app_can_interrupt(uint32_t msg_id, uint8_t dlc, const uint8_t *data)` is called to process a new CAN message.
* `void app_canvar_interrupt(uint8_t cv_id, uint32_t val)` is called to set a specific canvar.
* `void app_timer_interrupt(void)` is called every 10 milliseconds to advince time.

### Platform Operations

The following operations affect the platform:
* `void interrupt_disable(void)` disables interrupts. The above interrupt functions will no longer be called.
* `void interrupt_enable(void)` enables interrupts. The above interrupt functions will be called again.
* `void interrupt_wait(void)` waits for an interrupt to occur, then returns with interrupts enabled. It must be called with interrupts disabled to avoid possibly deadlocking.

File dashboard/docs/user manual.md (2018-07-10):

boot screen

## Introduction

Welcome to the user manual for the Einstein Motorsport Dashboard. The dashboard is designed to be easy to use, and customizable for any application. This User Manual describes how to use the dashboard's current firmware. You may also wish to read the [Programmer's Manual](https://github.com/tpwrules/emdash/blob/master/dashboard/docs/programmer%20manual.md) to understand how the firmware works, or the [Customizer's Manual](https://github.com/tpwrules/emdash/blob/master/dashboard/docs/customizer%20manual.md) to understand how to modify it.

## Main Screen

main screen

The main screen is divided into three sections:
* Car Information (green)
* Driver Information (blue)
* Mode Area (red)

### Car Information

This sections displays the measurements and status of the car's systems. Warning icons are displayed when certain thresholds are exceeded. When an icon is displayed, the corresponding measurement is drawn with inverted color.

Display of the section is handled by `src/warn.c`.

#### Measurement Description
The meaning of each measurement icon is described below. The table describes the icons in left to right, top to bottom order. The "Variable" column tells which canvar is monitored. The "Limit" column is the constant in `src/limits.h` which controls the value at which it should happen.

Variable | Limit | Displayed when
-------- | ----- | --------------
poil | LIM_OIL_PRESSURE_MIN | Oil pressure is too low.
tmot2 | LIM_WATER_TEMP_MAX | Cooling water temperature is too high.
pfuel | LIM_FUEL_PRESSURE_MIN | Fuel pressure is too low.
ub | LIM_BATTERY_MIN | Battery voltage is too low (as measured by ECU).
toil | LIM_OIL_TEMP_MAX | Oil temperature is too high.
tmot | LIM_BLOCK_TEMP_MAX | Engine temperature is too high.
tfuel | LIM_FUEL_TEMP_MAX | Fuel temperature is too high.
toil | LIM_OIL_TEMP_MIN | Engine oil temperature is too low.

### Driver Information

This area displays status and measurements important to the driver. Display of this section is handled by `src/drive.c`.

The following measurements are displayed:

* The RPM bar and current engine RPM (`nmot`) are displayed the top of the screen. When the current RPM exceeds the optimal RPM (illustrated by the black line), the entire screen flashes to prompt the driver to upshift. This is configurable in `src/limits.h` as well.
* Current gear (`gear`) is displayed in the center of the screen.
* If the upshift paddle on the wheel is pressed (`wb_upshift != 0`), an up arrow is displayed next to the gear indicator.
* If the downshift paddle on the wheel is pressed (`wb_downshift != 0`), a down arrow is displayed next to the gear indicator.
* If automatic shifting is enabled (`B_autoshiften_ems != 0`), AUTO is displayed below the gear indicator.
* Current speed (`speed`) is displayed above the gear indicator.
* If launch control is active (`B_launch != 0`), LAUNCH is displayed next to the current speed.
* If the radio button on the wheel is pressed (`wb_radio != 0`), a headset icon is displayed.
* Current traction control level (`wb_traction_knob`) is displayed at the bottom center of the screen.

### Mode Area

This area displays various other pieces of information, in several different modes. The mode is switched using the dash mode button on the wheel. The available modes are described below, in selection order.

CAN Status mode is handled in `canvar.c`, Firmware Version mode is handled in `src/version.c`, and all other modes are handled in `src/modes.c`.

#### Firmware Version

This page displays the firmware versions of the dashboard and wheelboard. The first number is the Git commit hash the firmware was built from, and the second number is the time it was built in YYYYMMddhhmm format. It is displayed briefly at startup, then the dashboard automatically switches to the next mode.

#### Clutch and Throttle

This page displays the clutch system pressure (`pclutch`). It also displays the position of the throttle pedal (???) and the throttle plate (`ath`).

#### CAN Status

This page displays the status of the CANBUS engine. If there is an error, this page is automatically shown. It also displays the current CPU usage of the dashboard processor. All messages will be processed, so high CPU usage will not result in incorrect operation. High CPU usage may slow down display updates; however, the latest data will always be shown. This is not a problem unless the CPU usage is 100% for long periods of time.

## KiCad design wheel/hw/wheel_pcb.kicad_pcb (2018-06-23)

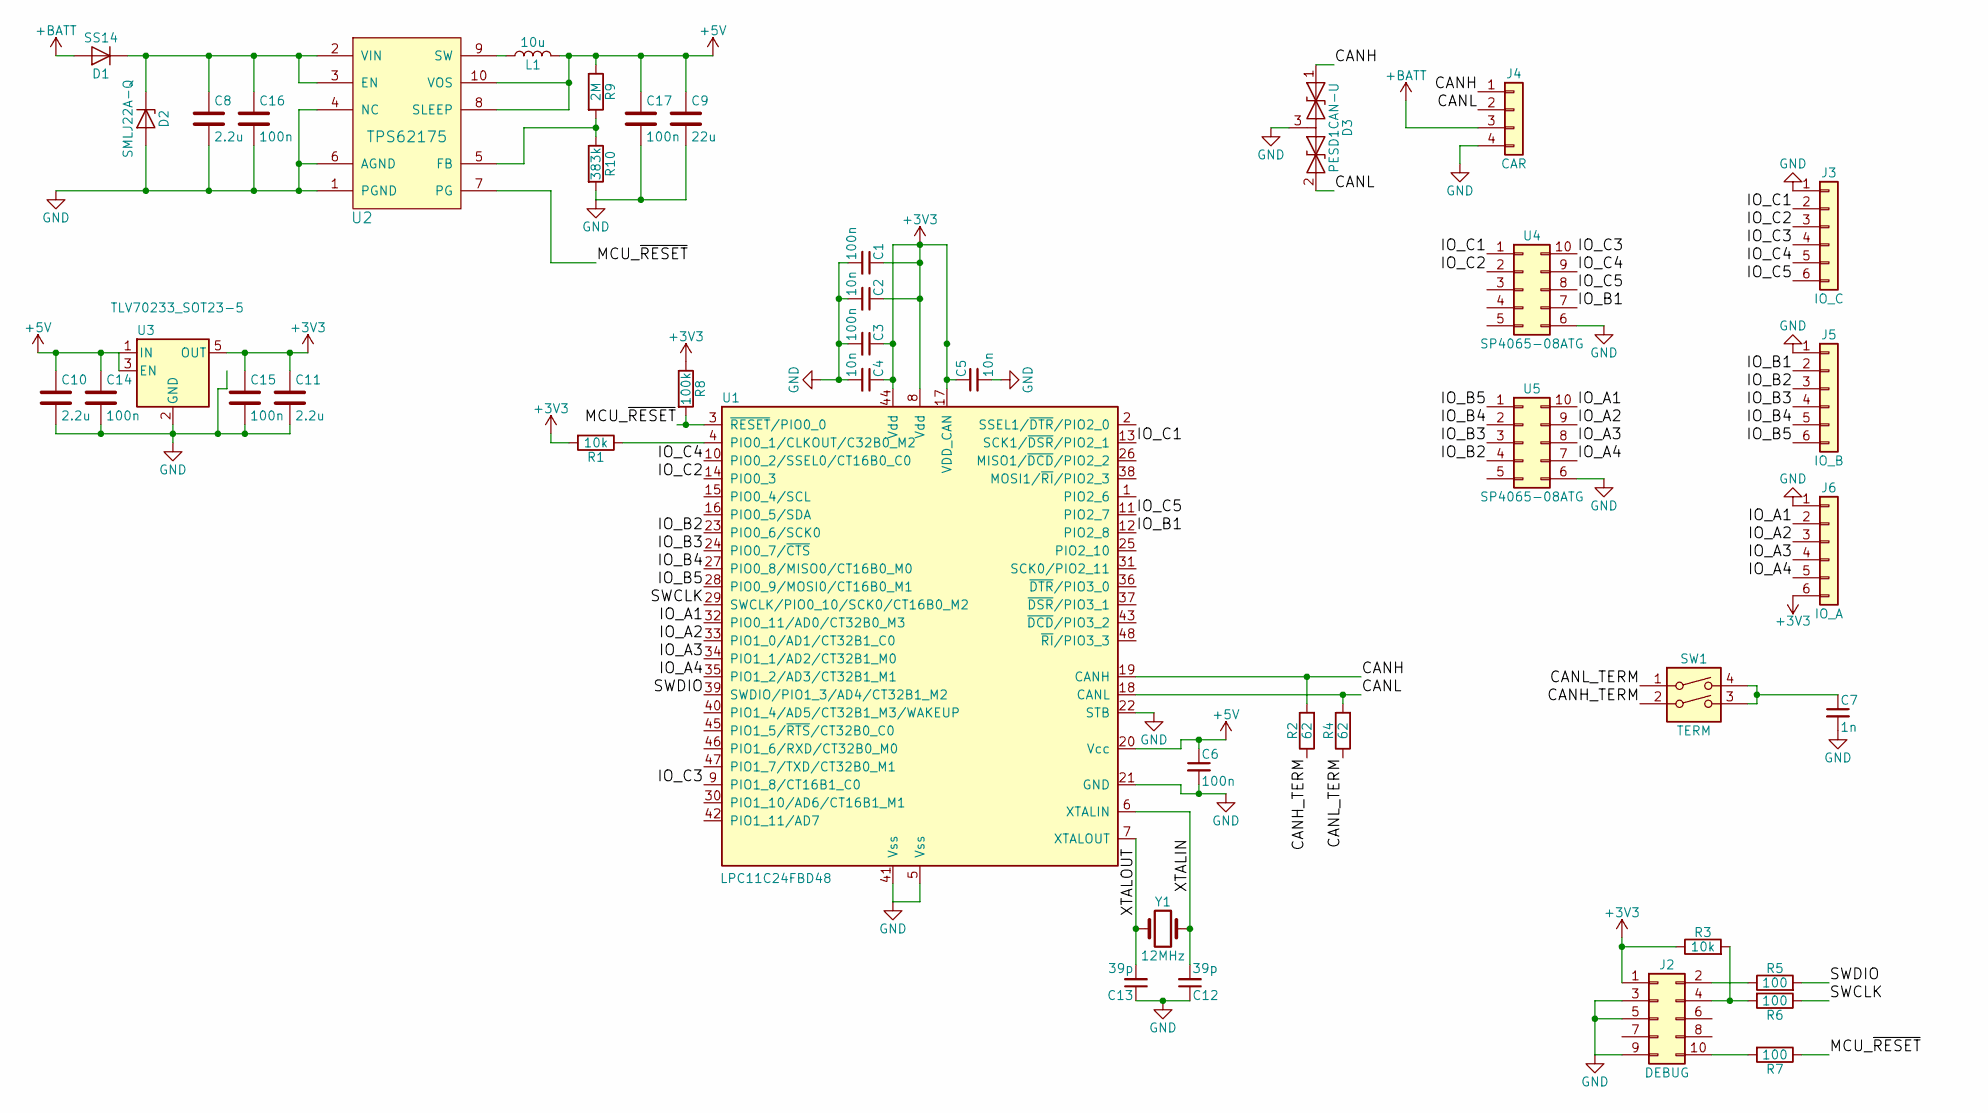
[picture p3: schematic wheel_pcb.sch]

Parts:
C1, C3, C6, C14, C15, C16, C17: 100n; C_0603
C2, C4, C5: 10n; C_0603
C7: 1n; C_0603
C8, C10, C11: 2.2u; C_0603
C9: 22u; C_0603
C12, C13: 39p; C_0603
D1: SS14; D_SMA_Handsoldering
D2: SMLJ22A-Q; D_SMC
D3: PESD1CAN-U; SOT-23
J2: DEBUG; Pin_Header_Angled_2x05_Pitch1.27mm_AMPHENOL_SHROUDED
J3: IO_C; Pin_Header_Angled_1x06_Pitch2.54mm
J4: CAR; Pin_Header_Angled_1x04_Pitch2.54mm
J5: IO_B; Pin_Header_Angled_1x06_Pitch2.54mm
J6: IO_A; Pin_Header_Angled_1x06_Pitch2.54mm
L1: 10u; Coilcraft_LPS4018
R1, R3: 10k; R_0603
R2, R4: 62; R_0603
R5, R6, R7: 100; R_0603
R8: 100k; R_0603
R9: 2M; R_0603
R10: 383k; R_0603
SW1: TERM; SW_DIP_x2_W7.62mm_Slide
U1: LPC11C24FBD48; LQFP-48_7x7mm_Pitch0.5mm
U2: TPS62175; DQC
U3: TLV70233_SOT23-5; SOT-23-5
U4, U5: SP4065-08ATG; MSOP-10_3x3mm_Pitch0.5mm
Y1: 12MHz; Crystal_SMD_HC49-SD

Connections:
+3V3: C1.1, C2.1, C3.1, C4.1, C5.1, C11.1, C15.1, J2.1, J6.6, R1.2, R3.1, R8.1, U1.8 (Vdd), U1.17 (VDD_CAN), U1.44 (Vdd), U3.5 (OUT)
+5V: C6.1, C9.1, C10.1, C14.1, C17.1, L1.2, R9.1, U1.20 (Vcc), U2.8 (SLEEP), U2.10 (VOS), U3.1 (IN), U3.3 (EN)
+BATT: D1.2 (A), J4.3
/CANH: D3.1 (A1), J4.1, R2.2, U1.19 (CANH)
/CANH_TERM: R2.1, SW1.2
/CANL: D3.2 (A2), J4.2, R4.2, U1.18 (CANL)
/CANL_TERM: R4.1, SW1.1
/IO_A1: J6.2, U1.32 (PIO0_11/AD0/CT32B0_M3), U5.10
/IO_A2: J6.3, U1.33 (PIO1_0/AD1/CT32B1_C0), U5.9
/IO_A3: J6.4, U1.34 (PIO1_1/AD2/CT32B1_M0), U5.8
/IO_A4: J6.5, U1.35 (PIO1_2/AD3/CT32B1_M1), U5.7
/IO_B1: J5.2, U1.12 (PIO2_8), U4.7
/IO_B2: J5.3, U1.23 (PIO0_6/SCK0), U5.4
/IO_B3: J5.4, U1.24 (PIO0_7/~CTS), U5.3
/IO_B4: J5.5, U1.27 (PIO0_8/MISO0/CT16B0_M0), U5.2
/IO_B5: J5.6, U1.28 (PIO0_9/MOSI0/CT16B0_M1), U5.1
/IO_C1: J3.2, U1.13 (SCK1/~DSR~/PIO2_1), U4.1
/IO_C2: J3.3, U1.14 (PIO0_3), U4.2
/IO_C3: J3.4, U1.9 (PIO1_8/CT16B1_C0), U4.10
/IO_C4: J3.5, U1.10 (PIO0_2/SSEL0/CT16B0_C0), U4.9
/IO_C5: J3.6, U1.11 (PIO2_7), U4.8
/MCU_~RESET: R7.1, R8.2, U1.3 (~RESET~/PIO0_0), U2.7 (PG)
/SWCLK: R6.1, U1.29 (SWCLK/PIO0_10/SCK0/CT16B0_M2)
/SWDIO: R5.2, U1.39 (SWDIO/PIO1_3/AD4/CT32B1_M2)
/XTALIN: C12.2, U1.6 (XTALIN), Y1.1
/XTALOUT: C13.2, U1.7 (XTALOUT), Y1.2
GND: C1.2, C2.2, C3.2, C4.2, C5.2, C6.2, C7.2, C8.2, C9.2, C10.2, C11.2, C12.1, C13.1, C14.2, C15.2, C16.2, C17.2, D2.2 (A), D3.3 (common), J2.3, J2.5, J2.9, J3.1, J4.4, J5.1, J6.1, R10.2, U1.5 (Vss), U1.21 (GND), U1.22 (STB), U1.41 (Vss), U2.1 (PGND), U2.4 (NC), U2.6 (AGND), U3.2 (GND), U3.4 (NC), U4.6, U5.6
unnamed: C7.1, SW1.3, SW1.4
unnamed: C8.1, C16.1, D1.1 (K), D2.1 (K), U2.2 (VIN), U2.3 (EN)
unnamed: J2.2, R5.1
unnamed: J2.4, R3.2, R6.2
unnamed: J2.10, R7.2
unnamed: L1.1, U2.9 (SW)
unnamed: R1.1, U1.4 (PIO0_1/CLKOUT/C32B0_M2)
unnamed: R9.2, R10.1, U2.5 (FB)

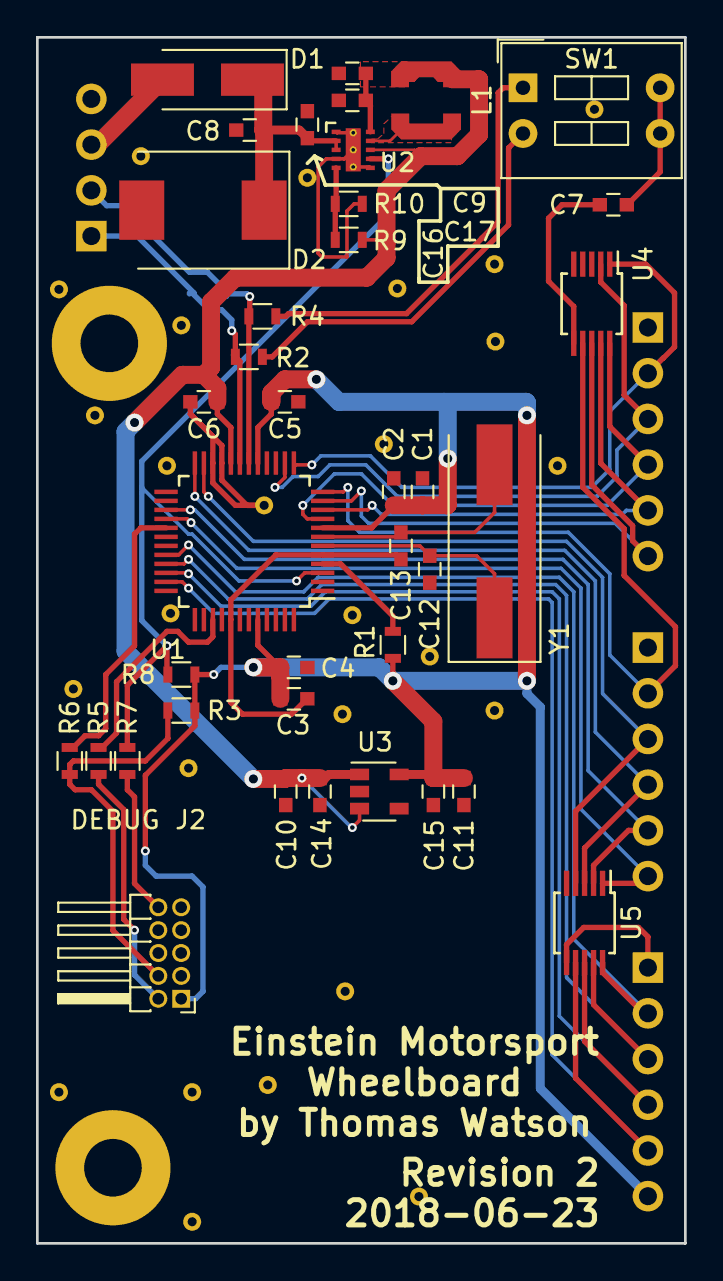
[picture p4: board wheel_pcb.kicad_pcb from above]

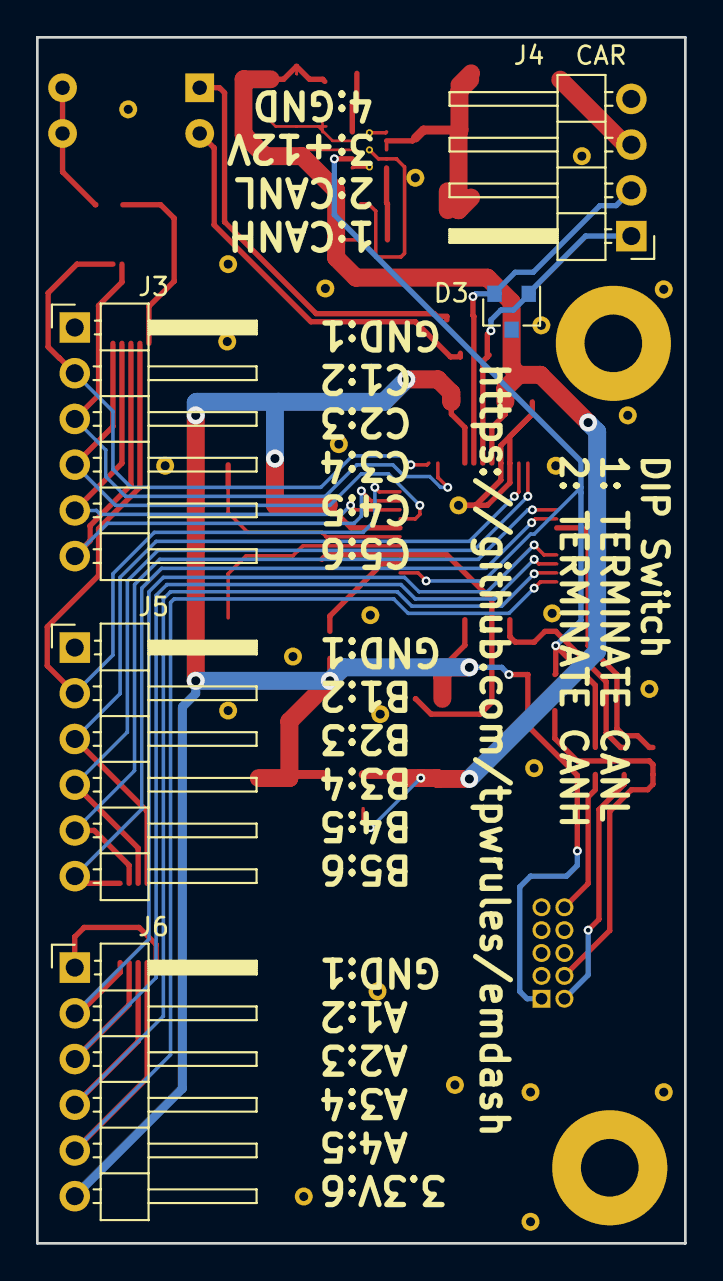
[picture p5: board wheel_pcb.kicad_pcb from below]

Board: 2 copper layers, 36.0 x 67.0 mm, 43 parts (5 on the bottom side), 35 nets.

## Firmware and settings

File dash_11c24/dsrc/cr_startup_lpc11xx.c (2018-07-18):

//*****************************************************************************
// LPC11xx Microcontroller Startup code for use with LPCXpresso IDE
//
// Version : 150706
//*****************************************************************************
//
// Copyright(C) NXP Semiconductors, 2013-2015
// All rights reserved.
//
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
// Permission to use, copy, modify, and distribute this software and its
// documentation is hereby granted, under NXP Semiconductors' and its
// licensor's relevant copyrights in the software, without fee, provided that it
// is used in conjunction with NXP Semiconductors microcontrollers.  This
// copyright, permission, and disclaimer notice must appear in all copies of
// this code.
//*****************************************************************************

#include "bootload_integrate.h"
// system ID that this image is for
// gets cast appropriately and put in the vector table
#define SYS_ID (BOOTLOAD_SYSTEM_ID_DASHBOARD)

#include "../src_gen/build_version.h"

#if defined (__cplusplus)
#ifdef __REDLIB__
#error Redlib does not support C++
#else
//*****************************************************************************
//
// The entry point for the C++ library startup
//
//*****************************************************************************
extern "C" {
    extern void __libc_init_array(void);
}
#endif
#endif

#define WEAK __attribute__ ((weak))
#define ALIAS(f) __attribute__ ((weak, alias (#f)))

//*****************************************************************************
#if defined (__cplusplus)
extern "C" {
#endif

//*****************************************************************************
#if defined (__USE_CMSIS) || defined (__USE_LPCOPEN)
// Declaration of external SystemInit function
extern void SystemInit(void);
#endif

//*****************************************************************************
//
// Forward declaration of the default handlers. These are aliased.
// When the application defines a handler (with the same name), this will
// automatically take precedence over these weak definitions
//
//*****************************************************************************
     void ResetISR(void);
WEAK void NMI_Handler(void);
WEAK void HardFault_Handler(void);
WEAK void SVC_Handler(void);
WEAK void PendSV_Handler(void);
WEAK void SysTick_Handler(void);
WEAK void IntDefaultHandler(void);

//*****************************************************************************
//
// Forward declaration of the specific IRQ handlers. These are aliased
// to the IntDefaultHandler, which is a 'forever' loop. When the application
// defines a handler (with the same name), this will automatically take
// precedence over these weak definitions
//
//*****************************************************************************
void CAN_IRQHandler (void) ALIAS(IntDefaultHandler);
void SSP1_IRQHandler (void) ALIAS(IntDefaultHandler);
void I2C_IRQHandler (void) ALIAS(IntDefaultHandler);
void TIMER16_0_IRQHandler (void) ALIAS(IntDefaultHandler);
void TIMER16_1_IRQHandler (void) ALIAS(IntDefaultHandler);
void TIMER32_0_IRQHandler (void) ALIAS(IntDefaultHandler);
void TIMER32_1_IRQHandler (void) ALIAS(IntDefaultHandler);
void SSP0_IRQHandler (void) ALIAS(IntDefaultHandler);
void UART_IRQHandler (void) ALIAS(IntDefaultHandler);
void ADC_IRQHandler (void) ALIAS(IntDefaultHandler);
void WDT_IRQHandler (void) ALIAS(IntDefaultHandler);
void BOD_IRQHandler (void) ALIAS(IntDefaultHandler);
void PIOINT3_IRQHandler (void) ALIAS(IntDefaultHandler);
void PIOINT2_IRQHandler (void) ALIAS(IntDefaultHandler);
void PIOINT1_IRQHandler (void) ALIAS(IntDefaultHandler);
void PIOINT0_IRQHandler (void) ALIAS(IntDefaultHandler);
void WAKEUP_IRQHandler  (void) ALIAS(IntDefaultHandler);

//*****************************************************************************
//
// The entry point for the application.
// __main() is the entry point for Redlib based applications
// main() is the entry point for Newlib based applications
//
//*****************************************************************************
#if defined (__REDLIB__)
extern void __main(void);
#else
extern int main(void);
#endif
//*****************************************************************************
//
// External declaration for the pointer to the stack top from the Linker Script
//
//*****************************************************************************
extern void _vStackTop(void);

//*****************************************************************************
//
// External declaration for LPC MCU vector table checksum from  Linker Script
//
//*****************************************************************************
WEAK extern void __valid_user_code_checksum();

//*****************************************************************************
#if defined (__cplusplus)
} // extern "C"
#endif
//*****************************************************************************
//
// The vector table.  Note that the proper constructs must be placed on this to
// ensure that it ends up at physical address 0x0000.0000.
//
//*****************************************************************************
extern void (* const g_pfnVectors[])(void);
__attribute__ ((used,section(".isr_vector")))
void (* const g_pfnVectors[])(void) = {
    &_vStackTop,                            // The initial stack pointer
    ResetISR,                               // The reset handler
    NMI_Handler,                            // The NMI handler
    HardFault_Handler,                      // The hard fault handler
    0,                                      // CRC of image, not including
                                            // 32 byte header
    0,                                      // Length of image, not including
                                            // 32 byte header
    0,                                      // Reserved
    __valid_user_code_checksum,             // LPC MCU Checksum
    (void (*)(void))SYS_ID,                 // System ID that image is for
    (void (*)(void))BUILD_VERSION_COMMIT,   // Version: commmit
    (void (*)(void))BUILD_VERSION_TIME,     // Version: build time
    SVC_Handler,                            // SVCall handler
    0,                                      // Reserved
    0,                                      // Reserved
    PendSV_Handler,                         // The PendSV handler
    SysTick_Handler,                        // The SysTick handler

    // Wakeup sources for the I/O pins:
    //   PIO0 (0:11)
    //   PIO1 (0)
    WAKEUP_IRQHandler,                      // PIO0_0  Wakeup
    WAKEUP_IRQHandler,                      // PIO0_1  Wakeup
    WAKEUP_IRQHandler,                      // PIO0_2  Wakeup
    WAKEUP_IRQHandler,                      // PIO0_3  Wakeup
    WAKEUP_IRQHandler,                      // PIO0_4  Wakeup
    WAKEUP_IRQHandler,                      // PIO0_5  Wakeup
    WAKEUP_IRQHandler,                      // PIO0_6  Wakeup
    WAKEUP_IRQHandler,                      // PIO0_7  Wakeup
    WAKEUP_IRQHandler,                      // PIO0_8  Wakeup
    WAKEUP_IRQHandler,                      // PIO0_9  Wakeup
    WAKEUP_IRQHandler,                      // PIO0_10 Wakeup
    WAKEUP_IRQHandler,                      // PIO0_11 Wakeup
    WAKEUP_IRQHandler,                      // PIO1_0  Wakeup
    
    CAN_IRQHandler,                         // C_CAN Interrupt
    SSP1_IRQHandler,                        // SPI/SSP1 Interrupt
    I2C_IRQHandler,                         // I2C0
    TIMER16_0_IRQHandler,                   // CT16B0 (16-bit Timer 0)
    TIMER16_1_IRQHandler,                   // CT16B1 (16-bit Timer 1)
    TIMER32_0_IRQHandler,                   // CT32B0 (32-bit Timer 0)
    TIMER32_1_IRQHandler,                   // CT32B1 (32-bit Timer 1)
    SSP0_IRQHandler,                        // SPI/SSP0 Interrupt
    UART_IRQHandler,                        // UART0

    0,                                      // Reserved
    0,                                      // Reserved

    ADC_IRQHandler,                         // ADC   (A/D Converter)
    WDT_IRQHandler,                         // WDT   (Watchdog Timer)
    BOD_IRQHandler,                         // BOD   (Brownout Detect)
    0,                                      // Reserved
    PIOINT3_IRQHandler,                     // PIO INT3
    PIOINT2_IRQHandler,                     // PIO INT2
    PIOINT1_IRQHandler,                     // PIO INT1
    PIOINT0_IRQHandler,                     // PIO INT0
};

//*****************************************************************************
// Functions to carry out the initialization of RW and BSS data sections. These
// are written as separate functions rather than being inlined within the
// ResetISR() function in order to cope with MCUs with multiple banks of
// memory.
//*****************************************************************************
__attribute__ ((section(".after_vectors")))
void data_init(unsigned int romstart, unsigned int start, unsigned int len) {
    unsigned int *pulDest = (unsigned int*) start;
    unsigned int *pulSrc = (unsigned int*) romstart;
    unsigned int loop;
    for (loop = 0; loop < len; loop = loop + 4)
        *pulDest++ = *pulSrc++;
}

__attribute__ ((section(".after_vectors")))
void bss_init(unsigned int start, unsigned int len) {
    unsigned int *pulDest = (unsigned int*) start;
    unsigned int loop;
    for (loop = 0; loop < len; loop = loop + 4)
        *pulDest++ = 0;
}

//*****************************************************************************
// The following symbols are constructs generated by the linker, indicating
// the location of various points in the "Global Section Table". This table is
// created by the linker via the Code Red managed linker script mechanism. It
// contains the load address, execution address and length of each RW data
// section and the execution and length of each BSS (zero initialized) section.
//*****************************************************************************
extern unsigned int __data_section_table;
extern unsigned int __data_section_table_end;
extern unsigned int __bss_section_table;
extern unsigned int __bss_section_table_end;

//*****************************************************************************
// Reset entry point for your code.
// Sets up a simple runtime environment and initializes the C/C++
// library.
//*****************************************************************************
__attribute__ ((section(".after_vectors")))
void
ResetISR(void) {

    //
    // Copy the data sections from flash to SRAM.
    //
    unsigned int LoadAddr, ExeAddr, SectionLen;
    unsigned int *SectionTableAddr;

    // Load base address of Global Section Table
    SectionTableAddr = &__data_section_table;

    // Copy the data sections from flash to SRAM.
    while (SectionTableAddr < &__data_section_table_end) {
        LoadAddr = *SectionTableAddr++;
        ExeAddr = *SectionTableAddr++;
        SectionLen = *SectionTableAddr++;
        data_init(LoadAddr, ExeAddr, SectionLen);
    }
    // At this point, SectionTableAddr = &__bss_section_table;
    // Zero fill the bss segment
    while (SectionTableAddr < &__bss_section_table_end) {
        ExeAddr = *SectionTableAddr++;
        SectionLen = *SectionTableAddr++;
        bss_init(ExeAddr, SectionLen);
    }

#if defined (__USE_CMSIS) || defined (__USE_LPCOPEN)
    SystemInit();
#endif

#if defined (__cplusplus)
    //
    // Call C++ library initialisation
    //
    __libc_init_array();
#endif

#if defined (__REDLIB__)
    // Call the Redlib library, which in turn calls main()
    __main() ;
#else
    main();
#endif
    //
    // main() shouldn't return, but if it does, we'll just enter an infinite loop
    //
    while (1) {
        ;
    }
}

//*****************************************************************************
// Default exception handlers. Override the ones here by defining your own
// handler routines in your application code.
//*****************************************************************************
__attribute__ ((section(".after_vectors")))
void NMI_Handler(void)
{
    while(1)
    {
    }
}
__attribute__ ((section(".after_vectors")))
void HardFault_Handler(void)
{
    while(1)
    {
    }
}
__attribute__ ((section(".after_vectors")))
void SVC_Handler(void)
{
    while(1)
    {
    }
}
__attribute__ ((section(".after_vectors")))
void PendSV_Handler(void)
{
    while(1)
    {
    }
}
__attribute__ ((section(".after_vectors")))
void SysTick_Handler(void)
{
    while(1)
    {
    }
}

//*****************************************************************************
//
// Processor ends up here if an unexpected interrupt occurs or a specific
// handler is not present in the application code.
//
//*****************************************************************************
__attribute__ ((section(".after_vectors")))
void IntDefaultHandler(void)
{
    while(1)
    {
    }
}

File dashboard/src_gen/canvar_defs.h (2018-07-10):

#ifndef CANVAR_DEFS_H
#define CANVAR_DEFS_H

#include <inttypes.h>
#include "../src/canvar.h"

#define CV_ID_APS (0)
#define cv_aps (canvar_states[0])
#define CV_ID_WB_VERSION_COMMIT (1)
#define cv_wb_version_commit (canvar_states[1])
#define CV_ID_WB_VERSION_BUILD (2)
#define cv_wb_version_build (canvar_states[2])
#define CV_ID_WB_UPSHIFT (3)
#define cv_wb_upshift (canvar_states[3])
#define CV_ID_WB_DOWNSHIFT (4)
#define cv_wb_downshift (canvar_states[4])
#define CV_ID_WB_DASH_MODE (5)
#define cv_wb_dash_mode (canvar_states[5])
#define CV_ID_WB_RADIO (6)
#define cv_wb_radio (canvar_states[6])
#define CV_ID_WB_TRACTION_KNOB (7)
#define cv_wb_traction_knob (canvar_states[7])
#define CV_ID_PCLUTCH (8)
#define cv_pclutch (canvar_states[8])
#define CV_ID_B_AUTOSHIFTEN_EMS (9)
#define cv_B_autoshiften_ems (canvar_states[9])
#define CV_ID_B_LAUNCH (10)
#define cv_B_launch (canvar_states[10])
#define CV_ID_SPEED (11)
#define cv_speed (canvar_states[11])
#define CV_ID_NMOT (12)
#define cv_nmot (canvar_states[12])
#define CV_ID_ATH (13)
#define cv_ath (canvar_states[13])
#define CV_ID_GEAR (14)
#define cv_gear (canvar_states[14])
#define CV_ID_UB (15)
#define cv_ub (canvar_states[15])
#define CV_ID_TMOT (16)
#define cv_tmot (canvar_states[16])
#define CV_ID_TFUEL (17)
#define cv_tfuel (canvar_states[17])
#define CV_ID_POIL (18)
#define cv_poil (canvar_states[18])
#define CV_ID_TOIL (19)
#define cv_toil (canvar_states[19])
#define CV_ID_PFUEL (20)
#define cv_pfuel (canvar_states[20])
#define CV_ID_TMOT2 (21)
#define cv_tmot2 (canvar_states[21])
#define CV_ID_NOBUS_CAN_STATUS (22)
#define cv_nobus_can_status (canvar_states[22])
#define CV_ID_NOBUS_CPU_IDLE_PERCENT (23)
#define cv_nobus_cpu_idle_percent (canvar_states[23])

extern volatile canvar_state_t canvar_states[24];
extern const canvar_def_t canvar_defs[24];

#define CANVAR_NUM_VARS (24)
#define CANVAR_ID_MAP_COUNT (18)
extern const uint8_t canvar_id_map[18];

#endif

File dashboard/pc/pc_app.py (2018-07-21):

#!/usr/bin/env python3

import threading
import queue
import time
import numpy as np
import os

import sys

# in reality, the active area of the display is
# 127.15mm * 33.87mm
SCALE_FACTOR_INT = 3
SCALE_FACTOR_REAL = 2.715

if "realsize" in sys.argv[1:]:
    SCALE = SCALE_FACTOR_REAL
else:
    SCALE = SCALE_FACTOR_INT

do_can_logging = False
if "log" in sys.argv[1:]:
    do_can_logging = True

output_can = False
if "canout" in sys.argv[1:]:
    output_can = True

# import the shared library made by CFFI
from _pc_app import lib, ffi

# import the generator libraries we use
import sys
import os
# change directory to where this file is located
# so we can find the generator libraries
os.chdir(os.path.join(".", os.path.dirname(__file__)))
# add their directories to path
sys.path.append(os.path.join(os.path.abspath(".."), "pics"))
sys.path.append(os.path.join(os.path.abspath(".."), "can"))

# import the picture list
from piclist import piclist
# and canvar interface
import canvars

# exceptions are funky in callbacks
# exceptions raised in callbacks aren't on the main thread,
# so they will not kill the program
# this decorator solves that by sending a signal to the main thread
# so that everything dies gracefully
def term_main_thread(fn):
    def nfn(*args, **kwargs):
        try:
            fn(*args, **kwargs) # call function of interest
        except:
            import traceback
            import os
            import signal
            # print traceback before we die
            traceback.print_exc()
            # send SIGTERM to main thread
            os.kill(os.getpid(), signal.SIGTERM)
    # set new function name to the same as the
    # one being decorated, so that ffi knows
    # which it is still
    nfn.__name__ = fn.__name__
    return nfn

# set up interrupt stuff

# create a lock that is taken when an interrupt is happening
interrupt_busy_lock = threading.Lock()
interrupts_enabled = False
# and a lock to protect whether interrupts are enabled
interrupts_enabled_lock = threading.Lock()

def set_interrupt_state(enabled):
    global interrupts_enabled
    with interrupts_enabled_lock:
        if enabled:
            if interrupts_enabled == False:
                # release interrupt busy lock
                # to allow interrupts to happen
                interrupt_busy_lock.release()
        else:
            if interrupts_enabled == True:
                # acquire interrupt busy lock
                # to prevent interrupts from happening
                interrupt_busy_lock.acquire()
        interrupts_enabled = enabled

# start with interrupts turned off
# i.e. pretend an interrupt is happening
interrupts_enabled = False
interrupt_busy_lock.acquire()

# we create a condition variable for when an interrupt happens
# it is notified after every interrupt finishes
# when interrupt_wait is called, it waits for a notification
interrupt_happened = threading.Condition()

@ffi.def_extern()
@term_main_thread
def pc_interrupt_disable():
    set_interrupt_state(False)
lib.interrupt_disable = lib.pc_interrupt_disable

@ffi.def_extern()
@term_main_thread
def pc_interrupt_enable():
    set_interrupt_state(True)
lib.interrupt_enable = lib.pc_interrupt_enable

@ffi.def_extern()
@term_main_thread
def pc_interrupt_wait():
    with interrupt_happened:
        # enable interrupts so an interrupt we're waiting for
        # can actually happen. if interrupts are currently
        # disabled, we can't lose a notification because we hold the
        # interrupt_happened lock right now
        set_interrupt_state(True)
        interrupt_happened.wait()
lib.interrupt_wait = lib.pc_interrupt_wait

# the first interrupt is a timer
# which fires every 10 milliseconds
def timer_thread_func():
    next_time = time.perf_counter() + 0.01
    while True:
        with interrupt_busy_lock:
            lib.app_timer_interrupt()
            with interrupt_happened:
                interrupt_happened.notify_all()
        now = time.perf_counter()
        if now < next_time:
            time.sleep(next_time - now)
            next_time += 0.01
        else:
            next_time += 0.01 * int((now-next_time)/0.01 + 1)

timer_thread = threading.Thread(target=timer_thread_func, daemon=True)

# set up graphics emulation stiuff

# there is a queue of graphics operations which need to be acted on
gfx_ops = queue.Queue(maxsize=50)

NUM_TEXT_PAGES = 4
NUM_GRAPHICS_PAGES = 4

@ffi.def_extern()
def pc_scr_show_page(text, page):
    gfx_ops.put(("show",
        page + (NUM_GRAPHICS_PAGES if text else 0)
    ))
lib.scr_show_page = lib.pc_scr_show_page

@ffi.def_extern()
def pc_scr_clear_page(text, page):
    gfx_ops.put(("clear",
        page + (NUM_GRAPHICS_PAGES if text else 0)
    ))
lib.scr_clear_page = lib.pc_scr_clear_page

@ffi.def_extern()
def pc_scr_draw_rect(pixel_addr, w, h, color):
    page = (pixel_addr >> 12) & 0xF
    x = ((pixel_addr & 0x3F) * 6) + (pixel_addr >> 16)
    y = (pixel_addr >> 6) & 0x3F

    gfx_ops.put(("rect", page, 
        (x, y), (w, h), (0, 0, 0) if color else (255, 255, 255))
    )
lib.scr_draw_rect = lib.pc_scr_draw_rect

@ffi.def_extern()
def pc_scr_draw_pic(byte_addr, pic_id, inverted):
    gfx_ops.put(("pic",
        byte_addr >> 12, # page
        ((byte_addr & 0x3F)*6, (byte_addr >> 6) & 0x3F), # x, y
        pic_id, bool(inverted)
    ))
lib.scr_draw_pic = lib.pc_scr_draw_pic

@ffi.def_extern()
def pc_scr_draw_text(text_addr, text):
    gfx_ops.put(("text",
        (text_addr >> 9)+NUM_GRAPHICS_PAGES, # page
        ((text_addr & 0x3F)*6, ((text_addr >> 6)&0x7)*8), # x, y
        ffi.string(text)
    ))
lib.scr_draw_text = lib.pc_scr_draw_text

# set up can emulator

# set up can output logging
if do_can_logging:
    log_start_time = time.monotonic()
    flog = open("can_log.log", "w")

# set up can output if asked
canbus = None
can = None
if output_can:
    import can as can_import
    can = can_import
    canbus = can.interface.Bus(
        bustype='vector',
        app_name='emdash',
        channel=0,
        bitrate=500000)
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

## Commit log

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2018-04-15 more efficiently draw progress bar (and fix bugs with rect)
    [app.py]
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2018-04-16 add canvar system data files
    [Can_IDs_MS6_AL18.xlsx]
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2018-04-21 automatically switch away from showing version after a short delay
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2018-04-22 rework interrupt handling to be closer to correct
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2018-04-22 start kicad project for dashboard pcb
    [dash_pcb.kicad_pcb, dash_pcb.sch]
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2018-04-22 add LCD and debug connectors
    [dash_pcb.sch]
2018-04-22 implement design rules
    [dash_pcb.kicad_pcb]
2018-04-22 set up lcd shape as the pcb
    [dash_pcb.kicad_pcb]
2018-04-22 work on laying out LCD connector
    [dash_pcb.kicad_pcb, dash_pcb.sch]
2018-04-22 add new information about variables
    [Conversionlist_Thomas.xlsx]
2018-04-22 finish prototype lcd wire
    [dash_pcb.kicad_pcb, dash_pcb.sch]
2018-04-24 label a couple more required pins
    [dash_pcb.kicad_pcb, dash_pcb.sch]
2018-04-24 misnamed command data pin on lcd
    [dash_pcb.kicad_pcb, dash_pcb.sch]
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2018-04-27 add lcd driver which doesn't really work
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2018-04-27 fix graphics for 6x1
    [pc_app.py]
2018-04-28 fix gear pictures so that there's no longer overlap
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2018-04-29 add option to turn off auto mode cause it's currently crashy
2018-04-29 turns out it was probably a logic level issue; drive display module at 3v3 instead
    [dash_pcb.sch]
2018-04-29 update connectors for the lcd actually used
    [dash_pcb.kicad_pcb, dash_pcb.sch]
2018-05-01 fix various compiler warnings
    [build_pc_app.py]
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2018-05-04 rename can to cangen to avoid conflicts with python-can
    [cangen.py, pc_app.py]
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2018-05-06 add misc passives to dash pcb
    [dash_pcb.sch]
2018-05-07 add schematic symbol for lmz21700 power module
    [dash_pcb.sch]
2018-05-07 add tps62175 which we are actually using
    [dash_pcb.sch]
2018-05-07 wire up the 5v converter
    [dash_pcb.sch]
2018-05-07 add 3v3 power supply
    [dash_pcb.sch]
2018-05-07 add crystal to nxp
    [dash_pcb.sch]
2018-05-07 place new components relatively on board
    [dash_pcb.kicad_pcb]
2018-05-08 add led backlight 'driver'
    [dash_pcb.sch]
2018-05-08 rewire lcd to be easier to route
    [dash_pcb.sch]
2018-05-09 more parts shopping
    [dash_pcb.kicad_pcb, dash_pcb.sch]
2018-05-09 add footprint for TI power chip
    [dash_pcb.kicad_pcb, dash_pcb.sch]
2018-05-09 add footprint for contrast pot
    [dash_pcb.kicad_pcb, dash_pcb.sch]
2018-05-09 add footprint for inductor
    [dash_pcb.kicad_pcb, dash_pcb.sch]
2018-05-14 reset automatically when power isn't good
    [dash_pcb.kicad_pcb, dash_pcb.sch]
2018-05-14 lay out power bits
    [dash_pcb.kicad_pcb, dash_pcb.sch]
2018-05-14 lay out passives and xtal around the micro
    [dash_pcb.kicad_pcb]
2018-05-14 route out lcd connector
    [dash_pcb.kicad_pcb]
2018-05-14 route debug connector
    [dash_pcb.kicad_pcb]
2018-05-14 route power
    [dash_pcb.kicad_pcb]
2018-05-14 clean up
    [dash_pcb.kicad_pcb]
2018-05-15 correct custom component courtyards
    [dash_pcb.kicad_pcb]
2018-05-15 make shrouded version of programming connector
    [dash_pcb.kicad_pcb, dash_pcb.sch]
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2018-05-16 add test mounting hole
    [dash_pcb.kicad_pcb]
2018-05-16 use 4 position connector for car interface
    [dash_pcb.kicad_pcb, dash_pcb.sch]
2018-05-16 add jumpers to selectively terminate can bus
    [dash_pcb.kicad_pcb, dash_pcb.sch]
2018-05-16 pull reset to 3.3 instead of 5
    [dash_pcb.kicad_pcb, dash_pcb.sch]
2018-05-16 change termination jumpers to dip switches
    [dash_pcb.kicad_pcb, dash_pcb.sch]
2018-05-16 misc changes to part numbers and such
    [dash_pcb.sch]
2018-05-16 add bom
    [bom.xlsx]
2018-05-18 add mounting holes to match lcd
    [dash_pcb.kicad_pcb]
2018-05-18 crunch board a bunch
    [dash_pcb.kicad_pcb]
2018-05-18 crunch up 5v supply
    [dash_pcb.kicad_pcb, dash_pcb.sch]
2018-05-18 scrunch up 3.3v
    [dash_pcb.kicad_pcb]
2018-05-18 scrunch board edge and also 5v again by a lot
    [dash_pcb.kicad_pcb]
2018-05-18 improve grounding
    [dash_pcb.kicad_pcb]
2018-05-18 another 0.1 inches
    [dash_pcb.kicad_pcb]
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2018-05-18 copy dashboard to wheelboard
    [bom.xlsx, wheel_pcb.kicad_pcb, wheel_pcb.sch]
2018-05-18 remove dashboard specific parts
    [wheel_pcb.kicad_pcb, wheel_pcb.sch]
2018-05-18 preliminarily lay out and pin wheel connectors
    [wheel_pcb.kicad_pcb, wheel_pcb.sch]
2018-05-18 move connectors around to fit within constraints
    [wheel_pcb.kicad_pcb]
2018-05-19 relabel i/o with less lcd names
    [wheel_pcb.kicad_pcb, wheel_pcb.sch]
2018-05-19 clean up button bus
    [wheel_pcb.kicad_pcb]
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2018-05-19 add mounting holes to wheelboard
    [wheel_pcb.kicad_pcb]
2018-05-19 remove stray track and clean up tracks
    [wheel_pcb.kicad_pcb]
2018-05-19 wheel revision one gerbers
    [wheel_pcb-B.Cu.gbl, wheel_pcb-B.Mask.gbs, wheel_pcb-B.SilkS.gbo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]
2018-05-19 its gerber time almost for the dashbaord
    [dash_pcb.kicad_pcb]
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2018-05-27 add can bus error display
    [canvar_defs.h, pc_app.py]
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2018-06-16 missed a board ref
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2018-06-19 prevent timer interrupts from piling up
    [pc_app.py]
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2018-06-20 make 2 position slide switches instead of 4
    [dash_pcb.sch, wheel_pcb.sch]
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2018-06-20 draft layout of new wheel stuff
    [wheel_pcb.kicad_pcb, wheel_pcb.sch]
2018-06-22 rework some tracks
    [wheel_pcb.kicad_pcb]
2018-06-22 pretty much finish wheel layout
    [wheel_pcb.kicad_pcb]
2018-06-22 fix various silkscreen related transgressions
    [wheel_pcb.kicad_pcb]
2018-06-23 draft layout for dash board
    [dash_pcb.kicad_pcb]
2018-06-23 redo it but this time put the protection next to the input
    [dash_pcb.kicad_pcb, dash_pcb.sch]
2018-06-23 move lcd backlight next to power supply
    [dash_pcb.kicad_pcb]
2018-06-23 fix silkscreen
    [dash_pcb.kicad_pcb]
2018-06-23 add github link to boards
    [dash_pcb.kicad_pcb, wheel_pcb.kicad_pcb]
2018-06-23 add alternate part number for programming connector
    [dash_pcb.sch, wheel_pcb.sch]
2018-06-23 shrink crystal traces to reduce risk of solder accidents
    [dash_pcb.kicad_pcb]
2018-06-23 misc preparations incl better silkscreen and grounding
    [dash_pcb.kicad_pcb, wheel_pcb.kicad_pcb]
2018-06-23 bump revision to 2 and plot it
    [dash_pcb-B.Cu.gbl, dash_pcb-B.Mask.gbs, dash_pcb-B.SilkS.gbo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]
2018-06-25 update bom for new revision
    [bom dash.xlsx, bom wheel.xlsx, bom.xlsx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]
2018-06-26 fix battery conversion function and update desired battery limit
2018-06-29 fix cangen bugs and add new cangen type
    [cangen.py, canvar_defs.h]
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2018-07-02 add bootloader which doesn't really do anything yet
    [cr_startup_lpc11xx.c]
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2018-07-03 make boot code able to reboot the chip
    [cr_startup_lpc11xx.c]
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2018-07-09 put system id in header so user doesn't have to choose when bootloading
    [cr_startup_lpc11xx.c]
2018-07-09 add lpc chip lib to repo so it doesn't have to be tracked down and changed etc
    [uart_11xx.c]
2018-07-09 fix random warning in chip lib
    [uart_11xx.c]
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2018-07-09 correctly cast system id for vector table to eliminate warning
    [cr_startup_lpc11xx.c]
2018-07-09 apparently filters can leak. implement our own solution
2018-07-09 fix hysteresis when powered on in the dead zone
    [button_read.c]
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2018-07-18 niceify a couple of error messages in pc boot
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2018-07-20 rework hysteresis code to be a bit easier to understand
    [button_read.c]
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
